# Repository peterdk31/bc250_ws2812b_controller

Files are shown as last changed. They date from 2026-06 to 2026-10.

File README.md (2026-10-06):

# Serial LED controller

A Linux daemon that renders WS2812 (NeoPixel) effects on the host and streams
the frames over USB serial to an ESP32, which just clocks them out to the strip.
All the logic — sensors, rules, effects — lives on the host, so changing
behavior never means reflashing the microcontroller.

Built for an AMD BC-250 running its case lighting from CPU temperature and load,
but nothing is board-specific. Co-authored with
[Claude](https://claude.com/claude-code) (Anthropic).

```
host (led daemon)                      ESP32              strip
sensors → rules → effect → frames ──serial──→ SPI/DMA ──→ WS2812
```

## Hardware

- An ESP32 or ESP32-C3 dev board over USB (`/dev/ttyUSB0` or `/dev/ttyACM0`).
  **Prefer the C3**: its native USB lets the firmware tell whether the host is
  actually running, so the boot animation also plays on reboots and on machines
  that keep standby power on their USB ports. A plain ESP32 can't see any of
  that over UART and only plays it after a true power cycle (see
  [How it works](#how-it-works)).
- A WS2812/WS2812B strip: data to the GPIO set as `strip.pin` (default 13), plus
  5 V and GND from a supply that can handle it (not the board's regulator; share
  grounds).
- Optionally, a momentary power button and a wire to the PSU's PS_ON# line —
  the receiver can then stand in for the PS_ON→GND jumper an ATX/FSP supply
  needs before it starts (see [Power switch](#power-switch)).
- For the BC-250 there is a small carrier PCB in
  [`hardware/bc250_carrier`](hardware/bc250_carrier/README.md): the C3 Super
  Mini solders onto it, the PSU's 10-pin Mini-Fit Jr plug goes straight onto
  a header, and the strip, button, sense wire and four PWM fan headers each
  get a labelled connector — the power switch, strip and fan wiring below, on
  one board.

## Getting started

Two things are needed on the host:

- **`g++` and `make`** to build the daemon. On CachyOS (or any Arch) they come
  in the `base-devel` package group.
- **`esptool`** to flash the receiver (plus `curl`, which is preinstalled).
  You do **not** need an ESP32 toolchain — `make flash` downloads a prebuilt
  firmware image.

```sh
sudo pacman -S --needed base-devel    # compiler + make
pipx install esptool                  # ESP32 flasher (or: pip install --user esptool)
```

On Bazzite (immutable base image) `esptool` installs the same way, but
`g++`/`make` aren't in the base image — build the daemon inside a distrobox,
or copy a prebuilt `led` binary over.

Then build, flash, and start:

```sh
sudo make install                            # daemon + systemd unit + default config
sudo make flash                              # download prebuilt firmware + flash the ESP32
sudo systemctl enable --now led-controller
```

`make flash` reads the chip (`target`, default `esp32c3`) and port
(`serial.port`) from the config; override on the command line, e.g.
`sudo make flash PORT=/dev/ttyACM0 TARGET=esp32`. It stops the service during the
write and restarts it after.

### The full BC-250 flash

Everything this repo can put on the receiver — the ATX power switch, the PWM
fans, the BLE phone remote — is described in the config, in the blocks
`power_switch`, `fans` and `ble_remote` (each has its own section below).
`make flash` bakes all three into the receiver's small settings partitions the
same way it already bakes `strip.pin`, so the full flash is the plain one:

```sh
sudo make flash
```

The config is `/etc/led-controller/config.json` when it exists, else the
repo's (`CONFIG=path` overrides). The shipped blocks are all off, so a fresh
box writes all three features off — the shipped `power_switch` block carries
the carrier board's pins with `"enabled": false`, and an explicit `false`
*is* written. That matters only on a receiver whose power switch is already
on: written off, it releases PS_ON# and cuts the machine's power (see [Power
switch](#power-switch)). Flashing such a box from a config that has no
`power_switch` block at all leaves the chip's switch settings alone, so
delete the block, or enable it, before flashing a machine whose power
already hangs on the receiver. Writing the features from one file also arms
the encoders' strictest cross-checks: a pin claimed by two blocks, or by a
block and `strip.pin`, is a hard error. Each feature's section has the `flash-pwr` / `flash-fan` /
`flash-ble` target that rewrites just that block in seconds.

Finally, edit `/etc/led-controller/config.json` for your hardware — at least
`strip.leds`, `strip.pin`, and `serial.port` — then `sudo systemctl
restart led-controller`.

To try an effect directly (stop the service first, it holds the port):

```sh
led /etc/led-controller/config.json rainbow
```

This runs unprivileged once the serial-group membership added by `make install`
is active — that takes effect on your next login; before then, prefix `sudo`.

## How it works

The daemon renders every frame and sends it over serial; the receiver only
displays what arrives. Pin and LED count travel in each frame, so the firmware
is generic and never needs reflashing for a config or effect change.

While the daemon isn't driving the line — at cold boot before it starts, and
after it exits on shutdown — the receiver plays a **boot** and **shutdown**
animation from flash. The daemon renders those too (through the same color
pipeline), records them, and uploads them once at startup; the receiver stores
them and replays them. So editing the boot/shutdown effects also needs no
reflash — just a daemon restart. A fresh, never-recorded board stays blank
until the daemon has run once and uploaded the recordings.

*When* the boot animation plays depends on the board. It always runs from chip
reset until the daemon's first frame. On USB-native chips (the C3 and friends)
it also re-arms whenever the USB host goes away and comes back — the bus
keepalives stop for a few seconds and return — which covers a reboot (shutdown
animation, dark while the host is down, boot animation as it comes back up)
and a power-on where standby VBUS kept the receiver running the whole time. A
plain ESP32's UART carries no trace of the host's state, so it shows the boot
animation only when it genuinely loses power; on a reboot it stays dark after
the shutdown animation until the daemon returns. If the power-on animation
matters to you, get a C3.

The serial baud auto-negotiates: if bytes arrive but no frame decodes, the
receiver cycles through the supported rates until frames validate, then
remembers the working rate in flash. Changing `serial.baud` just needs a
service restart.

## Flashing the receiver

The firmware is a native [ESP-IDF](https://docs.espressif.com/projects/esp-idf/en/stable/esp32/get-started/)
project under `firmware/` (no arduino-cli, no `.ino`). CI builds it for each
target and publishes merged images to GitHub Releases; `make flash` downloads
the one for `TARGET` and writes it — no toolchain needed.

```sh
sudo make flash                     # download prebuilt image + flash (default)
sudo make flash FW_RELEASE=v1.0.0   # pin a release instead of latest
```

The image is written at `0x0` and doesn't touch the NVS or LittleFS partitions,
so a reflash keeps a board's saved state.

**Building from source** is only needed to modify the firmware, or to bake a
non-default `serial.baud` / `host_timeout_ms` into it. It builds inside
Espressif's ESP-IDF container (needs `docker` or `podman` — nothing is installed
on the host, and `make receiver-clean` drops the cached image), or against a
native ESP-IDF if you set `IDF_PATH=...`:

```sh
sudo make flash-source              # build (container/native) + flash
make receiver                       # build only, no flash
```

**Clearing the board's saved state** — the reset switch when the receiver acts
as if it remembers something wrong. Each erases one partition region; the app
and the power-switch wiring (`pwrcfg`) are untouched:

```sh
sudo make clear-nvs                 # remembered baud + strip geometry
sudo make clear-recordings          # stored boot/shutdown animations
```

The daemon re-uploads the recordings on its next start (and the receiver
re-formats the partition), so `clear-recordings` is also how you get past a
stale or half-written slot that the skip-unchanged hash check would otherwise
keep. As with flashing, esptool resets the chip — see the caveat under
[Power switch](#power-switch).

### Receiver debug log

The receiver has no console (the link is the daemon's), so it keeps a small log
ring in RAM and hands it back over the link on request. Set

```jsonc
"serial": { "debug_log": true }
```

and its lines appear in `journalctl -u led-controller` — the recording uploads
and where they went, boot/shutdown replays, host-gone/host-back transitions, the
strip blanking on timeout, and the power switch's own decisions. The ring is in
RAM on a board running from 5VSB, so events logged while the host was down (a
follow-down, a boot replay) drain once the daemon is back. With the flag off the
daemon never asks and the receiver never sends a log line — the only thing it
ever says unprompted is a power-button request (see
[Power switch](#power-switch)).

## Configuration

`/etc/led-controller/config.json`. The first half describes the receiver — the
chip, the link, and everything it does on its own when the daemon isn't
running — the second half the host's rendering:

```jsonc
{
    "target": "esp32c3",        // chip to build/flash for (esp32, esp32c3, ...)
    "serial": {
        "port": "/dev/ttyUSB0", // "none" or "" (or LED_PORT=none) runs headless;
        "baud": 921600,         // omitting the key defaults to /dev/ttyUSB0
        "debug_log": false      // drain the receiver's log to journalctl
    },
    "host_timeout_ms": 5000,    // receiver blanks after this long with no frame —
                                // baked into the firmware by `make flash-source`
                                // only; the prebuilt image always uses 5000
    "power_on": { ... },        // boot/shutdown animations the receiver replays
    "shutdown": { ... },        // (standalone effects only, see below)

    "power_switch": {           // the ATX power button, see Power switch
        "enabled": false,           // enabled + pins: flash-time (make flash-pwr)
        "hold_seconds": 2,          // hold this long for a hard cut     ┐ the four tunings:
        "boot_timeout_seconds": 10, // rail not up by then = release PS_ON# │ live (reload, or
        "sense_low_mv": 800,        //                                     │ the phone's cog
        "sense_high_mv": 2000,      //                                     ┘ on the Power tab)
        "pins": { "ps_on": 3, "button": 1, "button_gnd": null, "sense": 2, "led": 8,
                  "wake": null },   // wake: an OpenPuck's power-on pulse, see Power switch
        "short_press": null         // what the daemon runs on a short press,
                                    // e.g. "systemctl poweroff"; null = ignore it
    },
    "ble_remote": {             // the phone power button + dashboard, see BLE remote
        "enabled": false,
        "name": "BC250",
        "token": ""                 // 8-16 chars; readable by anyone with a shell here
    },
    "fans": [                   // the fans, see Fans — each an input, a curve
        { "name": "pump", "output": "header1",               // and an output (a receiver
          "input": "fallback", "fallback": 65, "boost": 100 }, // header, a pin, or the
        { ... }                                              // host's own pwm output)
    ],

    "strip": {
        "leds": 58,
        "pin": 13,              // ESP32 GPIO driving the strip
        "reverse": false,       // flip so LED 0 is at the far end
        "brightness": 0.2,      // 0..1, linear
        "gamma": "2.2",         // one value, or three ("2.0 2.2 2.4") per R/G/B
        "white_balance": "ffb0f0" // RRGGBB neutral-white gain; ffffff = off
    },
    "sensors": [ ... ],         // hwmon candidates, see Sensors
    "rules": [ ... ]
}
```

Configs from before September 2026 had an `esp32` block and a `sinks.serial`
one; the daemon names the old key and what it became, and exits, rather than
run on a half-read file.

### Checking a config

```sh
led --check /etc/led-controller/config.json   # or: make check
```

Would the daemon start on this file, and is it the file you meant to write?
The check parses it and runs every block through the same validation the
daemon does at startup — retired keys, the fans block, the rules and their
conditions and effect names, the boot and shutdown recordings (rendered, so a
segment that can't record is caught here) — and then the things the daemon
would run on but nobody could have intended: a key that isn't one inside
`serial`, `strip`, `power_switch`, `ble_remote`, a rule or a recording
segment (with a "did you mean" for a near miss), a value of the wrong type, a
color that isn't `RRGGBB`, a LED count over the receiver's 100, an inverted
sense hysteresis, an enabled `ble_remote` without a token. Each is a line
naming the key; any of them fails the check (exit 1). A `note:` line is
something to look at that may be intended — a top-level key the daemon
doesn't read by name (effects see every top-level key as a shared default
setting), or a rule below a catch-all that can never be reached — and
doesn't fail it. It opens no port and sends nothing; the sensor lookups only
say "not found yet" on a box without them.

`make install` runs the check on the deployed file with the freshly built
daemon before it swaps the binary and restarts the service, so a key the new
version retired is reported while the old daemon still runs, not as a crash
loop after; `make install CHECK=0` skips that.

### Live reload

The running daemon watches its config file and picks up a save within a
second or two — rules, effects, sensors, strip settings, the fans block —
with no restart. A change confined to the `fans` or `power_switch` blocks
leaves the running effect alone; anything else drops the current effect and
the matching rule starts afresh (a crossfade on the strip, like any other
switch). `systemctl reload led-controller` (SIGHUP) does the same
immediately. A file that doesn't parse or validate is reported in the journal
and the running config is kept, so a typo costs a log line rather than a
crash loop; fix it and save again. Two things still need more than a reload:
the `serial` block, because the port is opened once (the daemon says so when
it changes; restart), and anything flash-time on the receiver — the power
switch's pins and enable, the board's fan header map, `ble_remote` — which
is `make flash`'s business (the fans' outputs are not: a reload moves them). The power switch's four tunings and `short_press` are
not flash-time: a reload pushes the tunings to the receiver and changes what
a press does at once. Editing `power_on`, `shutdown` or `strip` re-renders
and re-sends the boot and shutdown recordings, which holds the strip for
about a second. Edits from the phone's dashboard take a shorter path: they
are applied live and written into the file by the daemon itself (`fans`,
`strip`, a scene rule's `color`/`level`, the `power_switch` tunings and
`short_press`), which then treats the file's new mtime as its own doing
rather than a change to reload.

### Tuning the colors

`brightness`, `white_balance`, and `gamma` fold into one per-channel lookup
table applied on the host, so they cost nothing per frame.

How to read the values — every knob is per-channel, red green blue:

```
white_balance "b4b0f0"          gamma "1.9 1.8 1.7"
               ││││└┴─ blue            └┬┘ └┬┘ └┬┘
               ││└┴─── green          red green blue
               └┴───── red
```

Two rules cover every adjustment:

- **White balance scales a channel the same at every level.** Lower a pair →
  less of that color, from full white down to the dimmest glow. `ff` = leave
  the channel alone.
- **Gamma changes how a channel *fades*.** A higher number makes that channel
  die away faster as colors dim; full-on and off never move. `2.2` is
  neutral; you only need three different numbers when a tint appears *only*
  at low levels.

So: name the color the white is leaning toward, then move that channel —
down in `white_balance` if the tint is there at full brightness, up in
`gamma` if it only creeps in as things get dim.

Dial the knobs in by symptom, in this order:

1. **Everything too bright or dim for the room** → `brightness` (0..1).
2. **Full white looks tinted** → `white_balance`: lower the channel(s) of
   the tint. White leans green → lower the middle pair (`ffb0f0`). This is
   the strip+diffuser calibration; start from the diffuser table below.
3. **Full white is neutral, but dim white picks up a tint** →
   per-channel `gamma`: raise the tint's channel so it fades faster (dim
   white leans blue → `"2.2 2.2 2.4"`) — or equivalently lower the channel
   that's going missing (dim white leans blue because red drops out →
   `"2.0 2.2 2.2"`).

The `solid` effect exists for exactly this — it puts up a fixed test field
through the normal correction pipeline:

```bash
led /etc/led-controller/config.json solid    # full white: judge white_balance
```

Look, adjust the config, run again. For the gamma step you need *dim* white;
a forced effect has no rule settings, but effects fall back to top-level
config keys, so temporarily add `"level": 0.25` at the top level of the
config (next to `"strip"`) and run `solid` again. Remove it when done.

**From the couch, with the BLE remote:** the shipped config's first rule is
the same test field as a switch — a static color with a level, which doubles
as a plain light when it isn't tuning anything —

```jsonc
{ "if": "file:/tmp/led-static-color", "effect": "solid", "hold": 0,
  "settings": { "color": "ffffff", "level": 1.0 } }
```

— and the phone's dashboard shows every such `file:` rule as a **scene**
with a switch (README [BLE remote](#the-dashboard)). Switch "solid" on, drag
the white-balance sliders on the LEDs tab while looking at the strip
(each release applies to the live strip at once and lands in the config's
`strip` block), pull the scene's `level` slider down for the gamma step,
switch it off. The color picker on the scene changes the rule's `color`, so
the same switch tests a pure red or a warm white. Any `file:` rule with a
`color` or `level` setting gets the same controls; one without is just a
switch (the `/tmp/led-night` rule below, say). Put these rules first so they
win over everything else while on.

`white_balance` is the *total* correction — strip and diffuser combined into
one measured value. Starting points per diffuser (always confirm against
`solid` white):

| Diffuser | `white_balance` | Why |
|---|---|---|
| none / clear cover | `ffb0f0` | just the strip's own green excess |
| white (milky) | `ffb0f0` | near-neutral filter; scatters but barely tints — trim blue a touch (`ffb0e0`) if white reads cool |
| black / smoked film | `b4b0f0` | dark film passes red most, so take the bare-strip value and pull red down ~30% on top of it. Films vary a lot: one measured black window film landed at `b4ffff` instead — its green/blue cut cancelled the strip's own green excess. Pair with per-channel gamma (e.g. `"1.9 1.8 1.7"`) if dim white still drifts |

Low brightness costs no smoothness: the corrected values ride the wire with 8
extra fractional bits and the receiver rounds them away with a temporal dither
at its own strip-refresh rate (several hundred Hz — far above flicker fusion),
so dim gradients glide instead of stepping or shimmering. There is nothing to
configure; the old `dither` key is gone (this needs receiver firmware from the
same version — reflash once after updating). A change to `strip` re-renders
the boot/shutdown recordings so they carry the new colors — on a hand edit as
part of the reload, after a phone edit ten seconds after the last slider
moved (each re-render holds the strip for about a second).

### Sensors

`sensors` is an ordered list of `chip:label` hwmon candidates; the first present
wins (a bare chip name means its `temp1_input`). Used by `temp` conditions.
The daemon keeps rescanning until one appears. The default
covers the BC-250 (`k10temp:Tctl`, then the NCT6686D under either nct driver).
Two more kinds of candidate take the same slot: `pmbus:CPU VRM` / `pmbus:GPU VRM`
read the BC-250's VRM controller over I2C, and `file:/path` reads a file
holding one temperature — both described under [Fans](#fans), where they are
also fan sources.

### Rules

Evaluated top to bottom every 0.5 s; the first rule whose `if` holds wins. A rule
without `if` always matches (put a catch-all last). No match → strip dark.

```jsonc
{
    "if": "proc:gamescope & temp>75",
    "effect": "ember",
    "hold": 5,                       // min seconds since last switch (default 0)
    "for": 3,                        // condition must hold this long to count (default 0)
    "settings": { "speed": 1.4 }     // effect-specific
}
```

Switches crossfade over the top-level `crossfade_ms` (default 600; 0 =
instant). `for` is an on-delay on the condition: it has to have held for that
many seconds before the rule matches, so a brief load spike never starts a
load rule. Dropping out is immediate. `hold` is the blunter guard: no switch
*into* this rule until that long after the last switch, whatever the
conditions did meanwhile.

### Conditions

| syntax | true when |
|---|---|
| `always` | always |
| `temp>N` / `temp<N` | sensor temperature above/below N °C |
| `cpu_load>N` / `cpu_load<N` | CPU busy above/below N % (bare `cpu_load` = `>20`) |
| `gpu_load>N` / `gpu_load<N` | amdgpu busy above/below N % (bare `gpu_load` = `>20`) |
| `proc:NAME` | a process with that name is running (15-char kernel limit) |
| `steam_dl` | a Steam download is actively moving bytes |
| `audio_playing` | system audio is actually playing (see below) |
| `file:/PATH` | the file exists |
| `!COND` | negation |
| `A & B` | both hold |
| `A \| B` | either holds (`&` binds tighter; no parentheses) |

`file:` is the external control surface — `touch /tmp/led-night` to switch modes,
`rm` to switch back. A rule whose whole condition is one `file:` path is also
a **scene** on the phone's dashboard ([BLE remote](#the-dashboard)): a switch
the daemon flips by creating or removing that file, with a color picker or a
level slider when the rule's settings carry `color` or `level`.

The `steam_download` effect turns the strip into a live download progress bar
(percent driven by network throughput; green pulse at 100%). Reading other
users' Steam libraries needs the daemon running as root (the systemd unit does).

The `audio_*` effects visualise what's playing (combine them with `cycle` for
variety — they share one capture stream and auto-gain, so hopping between them
is seamless). The effects capture samples by spawning `parec` (or
`pw-record`) on the default sink's monitor while active; running as root
(the systemd unit does) lets it find the user session's PipeWire socket under
`/run/user/`.

The `audio_playing` condition costs nothing while the system is silent (one
procfs read per tick). Once anything is audible it asks the sound server for
its playback stream list (`pactl -f json list sink-inputs`, spawned
asynchronously about once a second): an uncorked stream means playing, corked
or none means paused/stopped. That verdict is immune to quiet passages inside
the music and reacts to pause/resume within a second or two. It is also the
only source of truth: if the list can't be fetched while audio is audible
(no `pactl`, no reachable session), the condition stays false and a note is
left on stderr. Placing the rule *below* the `load` rule means load takes the
strip whenever it's active and music has it otherwise — first matching rule
wins.

## Effects

| name | description | key settings (defaults) |
|---|---|---|
| `alarm` | urgent heartbeat throbbing from the center | `color` (ff0000), `pulses_per_second` (2) |
| `audio_music` | audio-reactive bloom from the center: loudness sets its reach, bass pumps it and sends crests to the tips | `palette` (4a00b4,e02090,ff9c28), `pulse` (0.8), `gain_seconds` (6) |
| `audio_ripple` | audio-reactive: each bass hit sends a wave crest with a luminous wake racing from the center to the tips, reflecting back off them, colors walking the palette per beat | `palette` (0030a0,00c0e0,8040ff), `travel_seconds` (1.0), `sensitivity` (1.0), `reflect` (0.6) |
| `audio_spectrum` | audio-reactive liquid analyzer: a spring-loaded bar grows from the strip start with the loudness, a meniscus shine on its tip, bass pumping its base and treble its tip, a peak dot falling back with a comet tail between hits | `palette` (00e6b4,3a56ff,ff2e88), `pump` (0.7), `bounce` (0.6), `peak_color` (ffffff) |
| `aurora` | slow drifting color curtains walking a palette | `palette` (10ff80,10a0ff,8040ff), `speed` (1.0) |
| `boot` | calm bloom from the center into a full wash, then exhales into a dim hold | `intro_seconds` (7), `color` (ffffff) |
| `breathe` | palette wash on a slow breath with a drifting bright band | `palette` (0d4a44,30e090), `period_seconds` (3.5) |
| `button_off` | experimental: the lit strip collapses into the power button | `duration_seconds` (1.4), `color` (ffffff), `reverse` (true) |
| `button_on` | experimental: light spills out of the power button, then pulses | `spread_seconds` (2.5), `period_seconds` (4), `color` (ffffff) |
| `caustics` | underwater light caustics: two multiplied noise fields carve bright wandering filaments that merge and dissolve | `palette` (020818,004060,00b0c0,a0fff0), `sharp` (1.5), `gain` (3.2) |
| `comet` | Larson scanner with a fading tail, optional mirror | `palette` (8040ff,30c0ff), `sweeps_per_second` (0.7), `tail_pixels` (8) |
| `cycle` | rotates through a list of other effects | `period_seconds` (30), `effects` (list) |
| `drift` | soft palette glows wandering over a dark base | `palette` (2858ff,30d0b0), `blobs` (3), `speed` (1.4) |
| `ember` | slow warm aurora-style flow through an ember palette | `palette` (2a0a00,ff7d1e), `speed` (1.4) |
| `ink` | drops of ink recolor the whole strip in slow sweeping fronts, a glistening rim on each leading edge | `palette` (6a00ff,0080ff,00d0a0,ffb000,ff2060), `period_seconds` (10), `spread_seconds` (4) |
| `lava` | lava lamp: soft blobs drift, meet and merge into hotter spots | `palette` (ff0050,ff5a00,ffd000,00e5ff,7a00ff,ff00d0), `blobs` (4), `speed` (5.0) |
| `load` | CPU/GPU bars from center over a palette wash, each with a heartbeat that quickens under load; each side's palette window slides toward the hot end with its load | `palette` (00e0c0,2060ff,a040ff,ff4060,ff9000), `heat_span` (0.45), `color_drift` (0.3), `pulse` (0.5) |
| `load_boil` | CPU/GPU load as a lava lamp: each half's blobs boil harder and shift toward the palette's hot end with that side's load | `palette` (00e0c0,2060ff,a040ff,ff4060,ff9000), `blobs` (2), `boil` (2.5) |
| `orbit` | binary stars: glow pairs orbit a shared center, whipping through conjunctions that bloom white-hot | `palette` (1030ff,00d0ff,c080ff,ff40a0), `pairs` (2), `origin` (0.5) |
| `plasma` | drifting sines + noise walking a palette | `palette` (0040ff,00d0a0,c040ff,0040ff), `speed` (1.4) |
| `pulse` | soft palette rings expanding from the center | `palette` (5028ff,30d0ff), `period_seconds` (4) |
| `rainbow` | scrolling hue cycle with shimmer | `cycles_per_second` (0.9) |
| `shoreline` | waves roll in from both ends, decelerating and whitening into foam as they break at the center | `palette` (003048,00a090,60e0c0), `period_seconds` (6), `foam_color` (ffffff) |
| `shutdown` | CRT-style collapse to a point, then a slow phosphor fade | `duration_seconds` (5.0), `color` (0028ff) |
| `silk` | tide through a drifting warp field: color bands stretch, buckle and fold like fabric in a breeze | `palette` (3a1078,c03080,ff9040,20b0c0,3a1078), `fold` (0.5), `sheen` (0.3) |
| `solid` | fixed color everywhere — the color-calibration test field, or a plain static light | `color` (ffffff), `level` (1.0) |
| `steam_download` | live Steam download bar, green pulse at 100% | `palette` (d4009c,ff5a1e,ffd23c), `done_color` (00ff66) |
| `tide` | a palette gradient sliding and breathing | `palette` (102060,1890d0,30d0a0,8040ff,102060), `speed` (1.4) |

Colors are `"RRGGBB"` or `"#RRGGBB"`; a `palette` is several separated by
non-hex (`"2a0a00, ff7d1e"`), spaced evenly and blended in RGB. Every effect
also takes `frame_ms` (delay between frames; default 16 ≈ 60 fps).
Settings resolve per-rule first, then top-level config, then the defaults above.

### Boot & shutdown animations

Set `power_on` / `shutdown` to any standalone effect, or a `sequence` played
into one recording — typically a one-shot intro into a looping idle:

```jsonc
"power_on": {
    "sequence": [
        { "effect": "boot",    "record_seconds": 4,
          "settings": { "intro_seconds": 3, "color": "ff7818" } },
        { "effect": "breathe", "record_seconds": 5, "loop": true,
          "settings": { "palette": "2a0a00,ff7818", "period_seconds": 5 } }
    ]
},
"shutdown": { "effect": "shutdown", "settings": { "color": "0028ff" } }
```

The last segment's `loop` decides the tail (loop from its first frame, else hold
the last frame); earlier segments play once. For a seamless loop make the
looping segment's `record_seconds` a whole multiple of its period. The whole
recording replays at one rate — the first segment's `frame_ms` — so a later
segment's own `frame_ms` has no effect on replay. Finite
effects (`shutdown`) record to completion; open-ended ones (`boot`) record for
`record_seconds`. Unchanged recordings aren't rewritten to flash (a hash is
compared), so wear is near zero. `cycle` can't be a slot (it needs the JSON
config).

Preview a slot exactly as the receiver will replay it, without hardware:

```sh
make virtual-strip && ./virtual-strip                    # one terminal
LED_PORT=none ./led config.json --preview power_on       # another
```

## Power switch

An ATX/FSP supply (like the BC-250's FSP500-30AS) doesn't start until its
PS_ON# line (the green wire) is pulled to ground — normally a permanent
jumper. With the receiver powered from the PSU's **5VSB** standby rail, it can
drive that line instead and act as the machine's power button
(after [Thunkar/bc250-esp32-switch](https://github.com/Thunkar/bc250-esp32-switch),
minus its WiFi/BLE):

- **Press** the button while off → PS_ON# is sunk to ground, the PSU starts,
  the board boots. It fires on the press itself, not on the release, so that
  keeping it held afterwards is free to mean the failsafe below.
- **Short press** while the machine is up → the ordinary PC power-button
  gesture: the OS is asked to shut itself down gracefully. The receiver can't
  do that itself, so it asks over the link and the daemon runs the
  `power_switch.short_press` command (`"systemctl poweroff"`); the machine
  then powers itself off and the sense wire's follow-down releases PS_ON#.
  **This needs `short_press` set to a command** — it ships `null`, so a box
  that hasn't opted in ignores the press (and says so in the journal). If nobody answers within 3 s
  — daemon down, no OS yet, feature off — the request is dropped and the
  feedback LED blinks fast for a moment, because otherwise an unheard press
  looks exactly like a broken button. Nothing about this path touches PS_ON#:
  the worst case is a machine that stays on.
- **Hold** for 2 s while on → PS_ON# is released — a hard power-off for a
  wedged machine, and the answer to an OS that accepts the graceful request and
  then hangs. (Only a press that began while the machine was already up can do
  this: the press that powered it on never turns it back off, however long it's
  held.)
- With the **sense** wire (BC-250: TPMS1 pin 9, ~2.9 V while the board is
  up): a graceful OS shutdown is followed down (the sense line drops, the
  receiver releases PS_ON# so the PSU turns off too), and a board that never
  comes up within 10 s releases the PSU instead of leaving it energized.
  The wire is optional but strongly recommended — without it both are
  skipped, and after every OS shutdown the PSU stays energized, holding
  PS_ON#, until a 2 s long-press; what's left is less a power button than a
  toggle that sticks on.
- **Keep holding the button** → the failsafe: while it is physically held the
  sense line cannot power anything off. Follow-down is suppressed, and the boot
  timeout is parked, counting its 10 s from the release instead of from the
  power-on. This is the way out of a mis-wired sense line, which is otherwise
  self-sealing: a sense pin that reads low while the board is really up (wrong
  pin, wire fallen off, thresholds wrong) makes the boot timeout cut the PSU
  ~10 s into every boot, so the machine can never stay up long enough to
  reflash the config that would fix it. Press to power on, keep your finger
  down, and the machine stays up while you reflash — including *through* the
  reflash: a receiver that comes up with the button already held adopts that
  press as the failsafe, and won't read it as a fresh 2 s force-off either.
  The sense line is still sampled and logged while held (see the debug log
  below) — that log is how the right pin and thresholds get found.

Wiring (the shipped `power_switch.pins`, for the ESP32-C3; `null` = not wired):

| receiver pin | connects to |
|---|---|
| GPIO3 (`ps_on`) | gate of an N-channel MOSFET that sinks PS_ON# to ground (see note below) — **not** PS_ON# directly |
| GPIO1 (`button`) | momentary switch terminal A (internal pull-up, pressed = low) |
| `button_gnd`: `null` when the switch is wired to a real GND (the carrier board), else e.g. GPIO21 | switch terminal B — driven low as a local ground, so the button needs no run to a real GND. (GPIO21 is U0TXD: free while the host link is USB) |
| GPIO2 (`sense`, `null` = not wired) | optional board-power sense, e.g. BC-250 TPMS1 pin 9, which is the board's main **3.3 V rail**. Emphatically *not* pin 15 (`3VSB`): that stays up whenever PS_ON# is held, so it reads like a working sense wire and then never fires follow-down or the boot timeout. Read as an averaged ADC voltage with hysteresis (`sense_low_mv` / `sense_high_mv`); the ADC saturates near 3.1 V, so a healthy rail logs ~2.9–3.1 V |
| GPIO8 (`led`, `null` = none) | optional feedback: the board's own little LED *blinks* while the button reads pressed (and through a wake pulse), so the wiring can be eyeballed without a PSU. GPIO8 is the plain onboard LED on common C3 dev boards; a blink shows regardless of the LED's polarity |
| `wake` (`null` = not wired; GPIO20 on the carrier's J11) | optional **wake input**: a 3.3 V active-high pulse from another device that wants the machine on — see *Waking from an OpenPuck* below. Internal pull-down; a rising edge while OFF powers on, and a pulse in any other state is dropped, so it can never shut anything down. Because it can do nothing else, this is the one pin that also **moves at runtime**, like the tunings: the daemon pushes `pins.wake` at startup and on a reload, and the phone's power settings pick it from the receiver's free pins (see [The dashboard](#the-dashboard)) |
| 5VSB + GND | PSU standby rail, so the receiver runs while the machine is off — **read the warning below before also plugging in USB** |

> ⚠️ **Critical — 5VSB and USB at the same time.** In this role the receiver
> is powered from 5VSB *and* still plugged into the host's USB for the LED
> link. That is two hard-paralleled 5 V supplies: most dev boards tie the USB
> connector's VBUS straight to their 5 V pin, so whichever rail sits higher
> pushes current into the other with nothing to limit it. Whenever the
> machine is off — the normal state for a power button — that means the
> receiver back-feeds the host's **dead** USB port continuously: current
> flows backwards through the port's VBUS circuitry (which is not designed
> for it and can be damaged) and phantom-powers part of the motherboard's
> 5 V rail off the PSU's small standby supply. **Cut or unpin the 5 V wire
> (red) in the USB cable**; keep D+, D− and GND. The receiver then runs
> solely from 5VSB and USB still works fully as a self-powered device —
> flashing, the LED link and the USB host-presence detection are unaffected.
> Some dev boards do have a protection diode between the USB jack and the
> 5 V pin, which blocks the back-feed — but many compact clones don't, so
> don't bet the port on it.

**The PS_ON# pin drives a MOSFET, not PS_ON# directly.** A 3.3 V pad can't be
tied to PS_ON#: the line is pulled to 5 V inside the PSU, and letting it rise
back-feeds the pad's clamp diode so it never reaches a clean "off" — direct
drive doesn't work. Wire a small N-channel MOSFET (a **2N7000** is plenty for
PS_ON#'s ~1 mA) as a low-side switch: **gate** ← the `ps_on` pin, **source** →
GND, **drain** → PS_ON#. `ps_on` HIGH turns the MOSFET on and pulls PS_ON#
to ground (PSU on); LOW releases it (PSU off). Add a **gate pull-down (~100 kΩ,
gate → GND)** so the MOSFET stays off whenever the pad isn't driving it — at
power-up before the firmware runs, during a reset, and on the `"enabled": false` release
path; without it a floating gate could start the PSU on its own. (100 kΩ is
ample: the gate is a near-pure capacitance, and the line switches about once
per boot.)

```
ESP32-C3  (running on the PSU's 5VSB standby rail — see the USB warning above)
──────────────────────────────────────────────────────────────────────────────
  5V      ──  PSU 5VSB
  GND     ──  PSU GND
  GPIO4   ──  WS2812B strip DIN   (strip.pin)        ── the LED output; daemon-set
  GPIO3   ──  2N7000 gate         (pins.ps_on)       ── PS_ON# via MOSFET, below
  GPIO1   ──  button  N (common)  (pins.button)
  GPIO21  ──  button  NO          (pins.button_gnd)  ── or a real GND, and null here
  GPIO2   ──  BC-250 TPMS1 pin 9  (pins.sense)       ── board sense (3.3 V rail)
  GPIO8   ──  onboard LED         (pins.led)         ── feedback, no wiring
  GPIO20  ──  OpenPuck pin 017    (pins.wake)        ── optional wake pulse; null here

PS_ON# drive — low-side N-channel MOSFET (2N7000)
──────────────────────────────────────────────────────────────────────────────
                 PS_ON#   (PSU "green" wire; the PSU pulls it up to +5 V)
                    │
                    │ D (drain)
                 ┌──┴──┐
   GPIO3 ──┬─────┤ G   │   2N7000
           │     └──┬──┘   (N-channel)
       [100 kΩ]     │ S (source)
           │        │
          GND      GND

   GPIO3 HIGH → MOSFET on  → PS_ON# pulled to GND  → PSU ON
   GPIO3 LOW  → MOSFET off → PS_ON# floats to +5 V → PSU OFF
   The 100 kΩ gate→GND pull-down holds it OFF whenever GPIO3 isn't driving.

Button (momentary; N = common, NO = normally-open)
──────────────────────────────────────────────────────────────────────────────
   Pressing shorts N→NO. GPIO1 idles high on its internal pull-up; GPIO21 is
   driven low as the button's local ground, so a press pulls GPIO1 low.
   Press = power on (on the press edge), 2 s hold while up = force off, and
   held = sense failsafe.  (Wire N and NO — NOT the NC terminal.)

LED strip (WS2812B)
──────────────────────────────────────────────────────────────────────────────
   DIN ← GPIO4; the strip's +5 V and GND come from the PSU's main 5 V rail (a
   26-LED strip is more than the 5VSB rail should carry), sharing a common GND
   with the ESP32-C3. GPIO4 is the C3 build's value — the strip pin is the
   daemon's `strip.pin` (pushed at runtime, cached in NVS), not one of the
   `power_switch.pins`, so it just must not collide with the pins above or the C3's
   flash pins (GPIO12–17). The repo's default `strip.pin` is 4 to match the
   default `TARGET` (esp32c3); a plain ESP32 wants something like 13.
```

Three pin caveats. First, the sense pin is **GPIO2** — one of the C3's
strapping pins, and that's fine. It was briefly moved to GPIO0 on hygiene
grounds (TPMS1 pin 9 sits at 0 V whenever the machine is off, and Espressif
recommend pulling GPIO2 up for glitch immunity), which turned out to be a bad
trade: the theory was thin — the same design guidelines are explicit that on
the C3 GPIO2 *"does not determine SPI Boot and Joint Download Boot mode"*
(that's GPIO9, with GPIO8 supporting), and GPIO2 was verified booting fine on
real hardware with pin 9 grounded — while the cost of a default that doesn't
match the wire in the machine is severe, because a sense pin reading a rail
that isn't there means the boot timeout cuts the PSU 10 s into every boot (this
happened; the failsafe above exists because of it). So GPIO2 it is, and
`tools/pwrcfg.py` no longer warns about it. Severity *is* chip-specific,
though: on a plain ESP32 the strapping pins select boot mode outright (GPIO0
low = download boot), so there a sense line grounded half the time really can
stop the chip booting — the encoder still warns for those. Second, if the sense
wire isn't connected, set `"sense": null` rather than leaving the input
floating: a floating ADC pin reads noise, and the boot timeout may cut the PSU
seconds after every power-on. Third, the defaults are C3-specific: on a plain
ESP32, GPIO1/3 are its UART0 console and 0/2 are strapping pins — pick
different ones.

**Waking from an OpenPuck.** An [OpenPuck](https://github.com/safijari/openpuck)
(open firmware for a SuperMini nRF52840 that stands in for the Steam
Controller 2's puck) has a *ColdBoot* feature: when the paired controller's
Steam button is pressed while the host reads USB-unmounted, the puck drives a
GPIO high for 300 ms — on a motherboard, through a transistor across the
power-switch header. Here the receiver is the motherboard, so the transistor
goes: the puck's ColdBoot pin (silkscreen `017`, its default) straight to
the `wake` pin, puck GND to the GND beside it — both are 3.3 V logic. It
is a plain active-high edge, debounced like the button and read with the
internal pull-down, so an unplugged or unpowered puck reads idle. Two rules
make it safe to hang a stranger's output on the machine's power: it is
edge-triggered and **armed only after reading idle for 1 s** (both boards come
up together on 5VSB and the puck's pin floats until its firmware runs; a level
held high across a receiver reset is not a press), and a pulse in BOOTING or
ON is **logged and dropped** — on a PC that same pulse would mean "shut down",
here it can only ever mean "on", whatever the puck's own gating decides.
Build the puck with `EXTRA_FLAGS="-DOPK_PWR_SWITCH=1"`; its pulse polarity is
a build flag too (`PWR_SWITCH_ACTIVE`), and the receiver expects the default,
active-high.

Power the puck from 5VSB so it keeps listening while the machine is off: on
the SuperMini that is its **BAT** pin (the board has no pin on the USB side —
the Pro Micro "RAW" position is unconnected). BAT reaches the board's supply
node through a P-MOSFET that the host's USB VBUS switches off, and is isolated
from the USB connector by the charger and a Schottky (BAT60B), so 5VSB cannot
back-feed the host's port and the puck's USB cable stays **intact** — it must:
the nRF's VBUS pin sits on the connector side, and the host's VBUS dropping
when the machine dies is what clears OpenPuck's "USB mounted" gate. (This is
the one place the 5VSB-and-USB warning above does *not* apply; the receiver's
own dev board has no such diode.) 5 V on a charger's battery pin is off-label
but harmless — the charger sees a full cell and idles, the LDO takes up to
6 V; a 1N5817 in series brings it nearer a battery's voltage if that bothers
you. Once the machine's OS enumerates the puck it stops firing on its own; a
second Steam press during BIOS lands in BOOTING and is dropped.

The feature is **off until opted into**: its settings are the config's
`power_switch` block, and they live on the receiver in a small dedicated flash
partition (`pwrcfg`), not in the firmware image, so the prebuilt image works
and pins change without touching source. `make flash` writes the partition
from the block alongside a normal flash, and `make flash-pwr` writes *only*
that partition — re-pinning takes a couple of seconds and keeps the installed
firmware. Three guardrails to know about:

- **A config with no `power_switch` block leaves the chip's settings alone.**
  The fans and the remote are written *off* in that case, harmlessly; the
  power switch written off releases an asserted PS_ON# once the receiver
  reboots — it cuts the machine's power — so only an explicit
  `"enabled": false` does that. Put the jumper back first if the machine's
  power already hangs on the receiver.
- **The firmware must be v1.6.0 or newer** — that's where the `pwrcfg`
  partition first exists. `make flash-pwr` against an older installed
  firmware (or an older `FW_RELEASE` pinned) writes a sector that firmware
  never reads: a silent no-op. Update the firmware itself first. (Individual
  settings added later are simply ignored by firmware that predates them —
  e.g. v1.6.0 exactly reads everything but the `led` pin, and the `wake` pin
  needs the firmware from Sep 2026 on.)
- The block is validated before anything is written: `tools/pwrcfg.py`
  rejects pins the firmware would silently drop (nonexistent on `target`,
  SPI-flash or host-link pads, a non-ADC sense pin, a collision with the
  `strip.pin` LED data pin or a fan header) and nonsense tunings (inverted
  hysteresis thresholds), and an unknown or missing key. The receiver has no
  console, so a config it can't use would otherwise just look like a dead
  button.

```sh
sudo make flash          # firmware + the config's power_switch block (and the fans', and the remote's)
sudo make flash-pwr      # rewrite only the power_switch block: seconds
```

The switch runs standalone — no daemon involved; the button matters exactly
when the host is off. Only `short_press` is the daemon's.

Of the block, the **pins and `enabled` are flash-time only** — a pin the
machine's power hangs on is nothing to change from a phone, and the flash
tool is where the wiring gets checked. The four **tunings** are not:
`hold_seconds`, `boot_timeout_seconds`, `sense_low_mv` and `sense_high_mv`
are values the switch's task reads on every poll, so the partition's are
just their defaults. The daemon pushes the config's values to the receiver
at startup, on a [live reload](#live-reload) and after a phone edit
(command `0x0E`), the receiver applies them at once and keeps them in NVS
layered over the partition's — re-flashing `pwrcfg` with *different*
tunings wins again, the fans' rule — and the [BLE dashboard](#the-dashboard)
edits them from the Power tab's cog, against the sense wire's live reading.
`short_press` follows the same path on the daemon's side: a reload or a phone
edit changes what a press does without a restart.

**Reflashing caveat:** once the machine's power hangs on this pin, remember
that flashing the receiver *from that machine* resets the chip mid-write. On
a **C3** the firmware defends itself: the asserted level is latched in the
always-on pad domain (`gpio_hold_en`) so it rides through the chip's internal
resets — including into the flashing ROM — and on any reboot that isn't a true
loss of standby power the intent is restored first thing at boot, read from
NVS *or from the still-latched hold itself*, so even a reflash or `make
clear-nvs` that empties NVS can't talk the new firmware into releasing the
pin. (That double-check matters: `make flash` used to overwrite the NVS
region with the merged image's padding — it skips it now — and the freshly
booted firmware, finding no saved intent, would cut the machine's own power
at the end of the flash, hard enough to corrupt files on it.) Still, verify a
`make flash` on your wiring once — with a temporary PS_ON→GND jumper in
place — before trusting it with unsaved work. On a
**plain ESP32 neither defense works for flashing**: esptool resets it by
pulling the EN pin, a genuine chip power cycle that drops pad holds and reads
as a power-on reset. Flash one from another machine or with the jumper in
place. (Crashes/watchdog resets are still ridden out there too, provided
the PS_ON pin is one of its RTC-capable pins: 0, 2, 4, 12–15, 25–27, 32, 33.)
After a genuine 5VSB power loss the machine always stays off until the button
is pressed.

## Fans

The receiver drives up to six 4-pin PWM fans at the fan spec's 25 kHz —
built for an AIO liquid cooler, whose pump is just another 4-pin channel. The
fans are powered from the PSU directly (they draw far more than a GPIO ever
could); only their PWM input wires connect to the receiver, with all grounds
common. The receiver's 3.3 V push-pull output is comfortably above the spec's
~2.8 V logic-high threshold, so standard 4-pin fans read it fine; the fans'
tach (sense) wires stay unconnected. On the carrier board the four headers are
labelled FAN1–FAN4; elsewhere, see the wiring table below. The daemon can
also drive a fan header on the **host itself** — the BC-250's own, on the
NCT6686D — the way CoolerControl does (see [Host outputs](#host-outputs)).

Everything about the fans is the config's `fans` block: a list of fans, each
an **input** read through a **curve** onto an **output**. Every fan has a
`name`, an `output`, an `input` and a `fallback`, a `curve` for every input
but `fallback` (a parked fan's curve and fallback are optional — it drives
nothing), optionally a `boost`, and
optionally its tunings — `hysteresis`, `ramp`, `boost_seconds`. The list's
order is the phone's; there is nothing global in the block.

```jsonc
"fans": [
    {
        "name": "pump",             // log lines and the phone's card
        "output": "header1",        // the receiver's header 1 (FAN1 on the carrier)
        "input": "fallback",        // fixed speed: the fan runs its fallback, always — no curve
        "fallback": 65,             // AIO pumps want a steady 65-100
        "boost": 100,               // the duty for the first boost_seconds after power-on
        "boost_seconds": 5          //   (no boost key, or null = none; default 5 s)
    },
    {
        "name": "radiator",
        "output": "header2",
        "input": "temp",            // the top-level `sensors` pick, in °C
        "curve": "45:35 60:55 75:100",   // input:percent points, linear between, flat beyond the ends
        "hysteresis": 3,            // the temperature must fall this many °C before the fan slows (default 3)
        "ramp": 5,                  // max percent per second on the way down; speed-ups are immediate (default 5)
        "fallback": 100             // what it runs when the input can't be read, and when no daemon drives it
    },
    {
        "name": "exhaust",
        "output": "header3",
        "input": "gpio:0",          // the BC-250's own fan header's PWM wire, on receiver GPIO0: the
        "curve": "0:25 100:80",     //   RECEIVER reads it and runs this curve — daemon or no daemon.
        "ramp": 0,                  //   The board's firmware already smooths its output, so no ramp on top
        "fallback": 100
    },
    {
        "name": "board fan",
        "output": "nct6686:pwm2",   // the BC-250's own fan header, driven by this daemon (a host output)
        "input": "k10temp:Tctl",
        "curve": "50:30 80:100",
        "fallback": 60
    }
]
```

**`output`** is what the fan drives:

| output | drives |
|---|---|
| `headerN` | header N of the receiver's board — the board's header → GPIO map (`tools/pincheck.py` `FAN_PINS`; the carrier's FAN1–FAN4 = GPIO5, 6, 7, 10) |
| `gpio:N` | a receiver GPIO by number, for a hand-wired build |
| `chip:pwmN` | a pwm output of the host, driven by the daemon — see [Host outputs](#host-outputs) |
| `""` | nothing: the fan is *parked*, its settings kept for later. Its input still shows on the phone — a host fan header as the input (`"output": "", "input": "nct6686:pwm2"`) is how to watch what the board runs there, duty and rpm |

Every output is a runtime setting: the phone can move a fan to another header
or pin, and the receiver attaches its PWM there at once. The fans on receiver
outputs take the receiver's six PWM channels in list order. A receiver header
no fan names is **not driven** — and that is not "off": a 4-pin fan with a
floating PWM input runs at full speed, per the fan spec. A fan you want
*stopped* is one with `"input": "fallback", "fallback": 0` (most fans stop at
0 % duty; the spec allows a fan to keep a minimum speed instead, so check
yours).

**`input`** is what the curve reads; the x unit of the curve follows it, and
so does *where the curve runs* — on whichever side can read the input:

| input | reads | x unit | runs on |
|---|---|---|---|
| `fallback` | nothing — the fan runs its `fallback` value, always; no `curve` | — | receiver (a host output: daemon) |
| `gpio:N` | the duty of a PWM signal on the receiver's GPIO N — a fan header's PWM wire (the BC-250's own, say), so the receiver follows the board's BIOS curve with no daemon and the machine off. A receiver output only | % | receiver |
| `esp32_temp` | the receiver chip's own temperature sensor — a rough reading of the case air around the receiver (see below). The receiver runs the curve itself, with no daemon and the machine off. A receiver output only, on a chip with the sensor (the C3 yes, the plain ESP32 no) | °C | receiver |
| `temp` | the top-level `sensors` pick | °C | daemon |
| `chip:label` | any hwmon temperature, same syntax as `sensors` (`amdgpu:edge`, `nct6686:CPU`; a comma list of candidates works too). The phone's picker lists every labelled one the machine has, with its reading; so does `--fan-status` | °C | daemon |
| `pmbus:CPU VRM` / `pmbus:GPU VRM` | the BC-250's two VRM rails, read from the board's PMBus controller over I2C by the daemon itself — see [VRM and GDDR6 temperatures](#vrm-and-gddr6-temperatures) for the two-wire mod that exposes the bus. Listed in the picker once the controller answers | °C | daemon |
| `smu:VRAM hotspot` / `smu:VRAM average` / `smu:VRAM 0`..`7` | the eight GDDR6 chips — the hottest, the mean, or a named chip — through the `bc250_memory` kernel driver, or read from the SMU by the daemon when a patched BIOS has unlocked it; see [VRM and GDDR6 temperatures](#vrm-and-gddr6-temperatures). Code 80 saturates the sensor at 120 °C. Listed in the picker once patched | °C | daemon |
| `file:/path` | one temperature in a plain file, in millidegrees (the sysfs convention: 1000 and up) or degrees. For telemetry some other program publishes as files. Files under `/run/bc250` named `*_temp` are listed in the picker; any other path goes in through its *Temperature file…* row | °C | daemon |
| `chip:pwmN` | a hwmon pwm *output* — the board's own fan header, i.e. what its BIOS fan curve is asking for, read over the host instead of a wire. The phone's picker lists each one with its rpm. Not one the daemon drives (it would read its own duty back), so not the fan's own output either | % (0..255 read as 0..100) | daemon |
| `cpu_load` / `gpu_load` | the rule conditions' readings | % | daemon |

**`curve`** is `x:percent` points in one string (up to eight), linear
between points and flat beyond the ends, so a curve never has to spell out 0
or 100 on the x axis. Floors, ceilings and scaling all live in the curve
(`"0:25 100:80"` is a floor of 25 scaled to 80 %). A `fallback` input takes
no curve and every other input needs one (a parked fan's is optional) — the daemon (and
`make flash`) refuse the other combinations, along with an unknown or missing
key, so a typo is a startup error rather than a silently odd fan. A `gpio`
curve's inputs are whole percents 0..100, an `esp32_temp` curve's whole °C
0..100 (both travel to the receiver as bytes).

**`gpio:N`** as an input is the wired twin of `chip:pwmN`: a two-wire lead
from the fan header's PWM (pin 4) and GND pins to a free receiver GPIO and its
GND — only those two, never the header's +12 V, which would parallel the
board's fan rail with the PSU's. The receiver reads the pin with its internal
pull-up (a PC fan header drives its PWM open-drain, so the level is the
receiver's own 3.3 V; a push-pull 5 V driver needs a series resistor — check
with a meter), samples the duty four times a second, and runs the curve with
the fan's own `ramp`. Unplugged, the pin reads high — 100 %, the fan spec's
own answer to a missing signal. On the carrier board the free pins are GPIO0,
20 and 21 on J11 (each with a GND beside it; 20 and 21 are also the J5 UART
candidates), and `make flash` refuses anything else: a header's pin, another
fan's output, the strip, the power switch's pins, the flash pads, the USB
pair, and the strap pins (8, 9 — a PWM at 0 % is a pin held low at reset,
which is the download-mode strap). A pin that arrives at runtime (a phone
edit, a daemon push) is checked again on the receiver, which logs a refusal
and runs the fallback. The phone never has to guess: the receiver publishes
the pins that pass that check, for inputs and for outputs, and the editor
lists them.

**`esp32_temp`** reads the temperature sensor inside the receiver's own
chip — nothing to wire. It is the die's temperature, not the air's: the chip
sits a few degrees above the air around it (more with the radio busy), and
the offset varies from chip to chip, so treat it as a trend of the case air
near the receiver rather than a thermometer, and write the curve against what
it actually reads (the phone's picker shows it live). The receiver reads it
once a second and smooths it over ~8 s, so it has no `hysteresis` of its own
(the key is refused); `ramp` applies as usual. Its use is a curve that keeps
working with no daemon — a case fan that tracks how warm the box is, on a
bench build or while the host is booting — not a replacement for the host's
real temperatures. The page shows the reading whether or not a fan follows
it; a receiver with no sensor doesn't offer the input, and one that is sent
it anyway runs the fallback.

**`boost`** and **`fallback`** are the fan's *standalone* settings — what the
receiver does on its own. Full speed is the safe answer for cooling, which is
why `fallback` is 100 in most examples; a fan with no boost starts at its
fallback instead of boosting. Reading the radiator above as a timeline:

1. Power button pressed. The receiver asserts PS_ON#, sees the rail up, and
   runs the pump (which has a boost) at 100 % for `boost_seconds`.
2. Boost ends; the daemon isn't up yet, so the radiator runs its fallback,
   100 %.
3. The daemon starts, reads the temperature and pushes the curve's 35 %. The
   radiator settles there.
4. The temperature sensor stops reading (a driver unloaded, a thermistor
   unplugged): the radiator runs its fallback until it reads again.
5. The daemon crashes or is stopped under a running machine. Fifteen seconds
   later the receiver notices the silence and the radiator goes back to 100 %.
6. Normal shutdown. The daemon's shutdown notice says the machine itself is
   powering off, and the receiver *holds* the last live duties instead, so the
   fans wind down from where they are when the PSU cuts — no full-speed blip.
   (A plain `systemctl restart` or `stop` doesn't say that, and the fans fall
   back as in step 5 if no daemon comes back.)

The pump, a `fallback` input, runs 65 % from step 2 on and never notices the
daemon; the exhaust, a `gpio` input, follows the board's own fan header from
step 2 on the same way.

Each receiver fan's duty comes from four places, strongest first: the
**boost** while its window runs; the receiver's own **curve** for a `gpio`
or `esp32_temp` input; the daemon's **live** duty (a host curve's output, pushed on the 0.5 s
rule tick when it changes and refreshed every 5 s, never persisted); and the
**fallback**. With the power switch configured, "host powers on" means *its*
power-on event — the button press asserting PS_ON# — confirmed by the sense
wire reading the rail up, so a reset of the receiver itself (a crash, a
reflash, a daemon reconnect) never re-fires the boost. Without the power
switch, USB host presence stands in (debounced 3 s so a bus reset doesn't
re-fire it), else the boost fires once at receiver boot. Each fan's window is
its own `boost_seconds` long; no boost (or `boost_seconds: 0`) sits it out. A
boost is the receiver's, run before the daemon exists, so a host output has
none (the key is refused there).

**The fallback is a slider on the phone**, on every fan's card, and the
**output and input are pickers** in the card's editor; all of them write to
wherever the value lives. While a daemon is connected, to the daemon: into the
config file like every other edit, and the daemon pushes the standalone values
to the receiver. **With no daemon at all**, straight to the receiver (a control
op over BLE, nothing relayed to a host), stored in its flash so it survives
power cycles — and the pickers then offer just what a receiver runs by itself:
its headers and pins, and the `fallback`, `gpio:N` and `esp32_temp`
inputs. So the receiver is a fan controller on its own: every fan on it runs
its fallback or its own curve, the boost still primes a pump at power-on, and the phone dials, adds,
moves and removes them. That is the bench case (a carrier board, a PSU and
fans, no BC-250 booting) and the machine-off case too — dial the fans down at
night without waking anything. What the receiver can't do alone is a *host*
curve: it has none of the host's temperatures to read, so a `temp` or load fan
runs its fallback until a daemon connects. There is one source of truth, and it is the
config: a daemon connecting pushes the file's list over whatever the receiver
held — every output, `fallback`, `boost`, input kind and receiver curve — so a
fan dialled standalone lasts exactly until then, and the phone writes into the
file whenever a daemon is there.

**`hysteresis`**, **`ramp`** and **`boost_seconds`** are each fan's own, with
a default where the fan says nothing (3 °C, 5 %/s, 5 s): a board header
mirrored over `gpio:N` or `chip:pwmN` is already smoothed by the board's
firmware and wants `ramp: 0`, while the temperature curve next to it wants the
ramp — so each says for itself. Each applies to some fans only and is refused
on the rest, so a key that would silently do nothing is a startup error
instead: `hysteresis` to a temperature input (`temp`, `chip:label`, `pmbus:`,
`smu:`, `file:`), `ramp` to any input with a curve, `boost_seconds` to a fan
with a `boost`. The receiver runs `ramp` and `boost_seconds` itself (rounded
to whole units); `hysteresis` is the daemon's, since only its curves read a
temperature.

**The old shape is refused.** Until Sep 2026 the block was an object of
`header1`..`header6` blocks with a `source`; the daemon (and `led --check`)
now refuse it with the converted list printed, ready to paste over the old
block — `source` became `input`, each header's number became its `output`,
and the old `pins` override became `gpio:N` outputs. The `constant` input is
refused with a line saying it became `fallback`.

### Host outputs

A fan whose `output` is `chip:pwmN` is driven by the daemon writing the
host's own hwmon pwm output — the BC-250's fan header on the NCT6686D
(`fan2`/`pwm2` is the main fan header per the BC-250 docs; `--fan-status` and
the phone's picker show every output with the rpm of the tachometer beside
it, which tells the wired one). It works the way CoolerControl and lm-sensors'
`fancontrol` do: `pwmN_enable = 1` takes the output over (manual), `pwmN` is
the duty (0..255), and the value `pwmN_enable` held before (2 on the nct6687
driver: the board's own curve) is what hands it back.

It needs a driver that can *set* the output: the out-of-tree
[nct6687d](https://github.com/Fred78290/nct6687d) (`force=1`) can; the
in-kernel `nct6683` is read-only — the daemon then says so once, leaves the
output to the board, and the phone's card reads "read-only". Only one program
may drive an output: stop CoolerControl or `fancontrol` for the outputs the
config names (the daemon notices a pwm value it didn't write and says so).

Switching between the board and the host is the output, from the phone or the
file: a host output no fan names is the board's — park the fan (`"output": ""`)
to hand it back, and make the header its input to keep watching it there. A host output's `fallback` is what it runs while its input
can't be read; it has no `boost`.

**The board always gets its output back.** Every write to a `pwmN_enable`
goes through one place (`daemon/pwmout.hpp`), and:

- before an output is taken over, its name, its path and the `pwmN_enable` and
  `pwmN` values found are written to a claims record under the state dir
  (`/var/lib/led-controller/pwm-claims`, systemd's `StateDirectory`) and
  synced to disk — no record, no takeover;
- it is handed back — `pwmN` restored first, then `pwmN_enable`, read back to
  check (lm-sensors' `fancontrol` order) — whenever no fan drives it any more
  (an edit, a reload, a fan deleted), and on every exit the daemon runs code
  for; one that won't go back is set to full speed instead
  (`pwmN_enable = 0`, then manual at 255), never left at a low duty;
- `ExecStopPost=/usr/local/bin/led --release-fans` hands back whatever the
  record still holds after **any** stop — a crash, `kill -9`, the watchdog —
  and a starting daemon does the same before it claims anything;
- `WatchdogSec=30`: the main loop pings systemd, and a hung daemon is killed
  (then `ExecStopPost` runs), so a fan can't freeze at its last duty;
- a hwmon driver reloaded while an output is driven comes back under another
  `hwmonN` with the chip still in manual mode: the claim follows the output by
  name, so the values restored are the board's, never the daemon's own;
- every 5 s the output is read back: a `pwmN_enable` something else reset (a
  resume from suspend) is taken back, and the journal says so;
- a lock in the state dir keeps a second daemon (a `./led cfg aurora` beside
  the service) from touching the outputs; `--fan-status` and `--check` never
  do.

```sh
sudo led --release-fans                        # hand everything back by hand (a no-op while a daemon holds them)
cat /var/lib/led-controller/pwm-claims         # what is taken over right now (absent: nothing)
```

### VRM and GDDR6 temperatures

The BC-250's two voltage regulators (the CPU rail and the GPU rail) sit on
one PMBus controller at I2C address `0x60`, and each reports its own
temperature — the part of the board that gets hottest under load and that no
hwmon driver sees. The daemon reads them itself, no other service needed, as
`pmbus:CPU VRM` and `pmbus:GPU VRM`: a fan `input`, a `sensors` candidate for
the LED temp rules, and two rows in the phone's picker.

The bus has to be brought out first. `I2C_HEADER1` (3 pins: SDA, SCL, GND)
carries nothing on its own; the live SMBus is on the `TPMS1` debug header. Two
jumper wires bridge them: `I2C_HEADER1` **SCL → TPMS1 pin 4** (`SMB_CLK_MAIN`)
and **SDA → TPMS1 pin 6** (`SMB_DATA_MAIN`), no ground wire needed. The pinout
photos in [BC250-Telemetry's hardware guide](https://github.com/onlinermm/BC250-Telemetry/blob/main/hardware.md)
show exactly which pins; that project also worked out the controller's
register formats, which the daemon's reads follow. The kernel's `i2c-dev`
module is what makes the buses appear as `/dev/i2c-*`; `make install` lists
it for every boot (`/etc/modules-load.d/led-controller.conf`) and loads it
right away, so the wires are the only step. To see the bus yourself:

```bash
sudo i2cdetect -l                                            # the buses
sudo i2cdetect -y 4                                          # 60 should answer (usually bus 4)
```

The daemon finds the bus on its own: it probes every `/dev/i2c-N` for a device
at `0x60` whose output-voltage register reads sensibly (a read only — it writes
nothing to a bus that hasn't answered), logs `pmbus: VRM controller at 0x60 on
/dev/i2c-4`, and reads both rails every half second on a thread of its own
while a fan, a rule or a watching phone wants them. The rails are read only
while wanted, and a controller that stops answering (the wires came off) is
dropped and searched for again, the fan on its `fallback` meanwhile like
any lost sensor. If nothing answers on any bus, `--fan-status` shows the
input as `(not found)` and the daemon keeps looking every 30 s.

While a phone watches, the same controller's rail voltages and currents and
its 12 V input are read too, for the **Host power** card on the Power tab
([The dashboard](#the-dashboard)); nothing reads them otherwise.

The eight GDDR6 chips are a harder case. Nothing in the kernel reads them: the
value lives behind the SMU (the GPU's management microcontroller), which has no
stock command that returns it. The way around it — worked out by
[pan-Rijovich/bc250-memory-temperature](https://github.com/pan-Rijovich/bc250-memory-temperature)
and packaged by [BC250-Telemetry](https://github.com/onlinermm/BC250-Telemetry),
both MIT — is to upload a small program into the SMU and point an unused command
slot at it; that program then asks the memory controller for each chip. The
daemon does this itself, exposing the chips as `smu:` sources — no setting to
turn on; it works wherever it can and touches nothing where it can't:

```jsonc
"input": "smu:VRAM hotspot"     // the hottest chip
"input": "smu:VRAM average"     // the mean of the eight
"input": "smu:VRAM 3"           // one named chip, 0..7
```

```jsonc
"vram_temps_interval_ms": 1000  // optional, top level: how often to re-read (default 2000, floored at 250)
```

- **Nothing is opened until something asks** for an `smu:` reading — a fan's
  input, a rule, or the phone's sensor picker.
- **The `bc250_memory` kernel driver, when loaded, does the reading** (see
  below); the daemon then never commands the SMU.
- **Otherwise the SMU's secure-access gate must already be open**, done by a
  patched BIOS such as [RescueMei's DXEv3 build](https://github.com/RescueMei/BC250-DXEv3-BIOSMOD).
  The daemon does **not** run the unlock itself — that is an exploit, the risky
  half, and it belongs in firmware that runs once at boot. If the gate is
  closed the daemon says so once and offers no readings.

The default 2 s is well inside how fast a GDDR6 package heats (its thermal
time constant is tens of seconds), eight SMU commands every 2 s are nothing
next to a GPU governor sharing the window, and the kernel driver caches its
readings for 1 s, so reading faster gains nothing there.

The daemon also checks the board is a BC-250 on stock **P3.0** firmware (the
build the uploaded program was compiled against) and reads its own upload back
before trusting it. The patch lives in the SMU's RAM only and is gone on the
next reboot; the daemon re-applies it when asked. On anything that is not a
BC-250 the check fails before the SMU is opened, and the sources simply never
read. Code 80 is the sensor's
ceiling and reads as 120 °C, meaning "at least that" — set a VRAM curve's top
below 120. `--fan-status` prints whether the patch took and, if not, why (a
locked SMU, the wrong board or BIOS); the daemon logs the same to the journal.

**Running alongside a GPU governor.** The SMU is reached through one shared
register window (`0xB8`/`0xBC` on `00:00.0`), and an SMU GPU governor such as
[filippor/cyan-skillfish-governor](https://github.com/filippor/cyan-skillfish-governor)
(smu branch) drives the same window. That governor takes `flock` on the PCI
config file around its accesses, and the daemon takes the **same** lock around
each of its own, so the two coordinate rather than corrupt each other's
transactions. This makes concurrent use safe in the ordinary case. It is not a
hard guarantee — the governor locks per register access rather than per
address+data pair, so a residual race on its own writes remains — so keep the
read cadence modest (the 3 s default is fine; there is little reason to poll
VRAM temperatures fast) and, if you can, run only one SMU tool. A reader that
does **not** take the lock (BC250-Telemetry's own memory service) must not run
with the governor at all.

> **Risk.** The uploaded program waits on the memory controller with no timeout
> of its own, and this integration has not been validated on hardware. A wedged
> SMU may need a full power-off (standby included) to recover.

If you would rather not have the daemon touch the SMU, BC250-Telemetry's own
memory service publishes the same readings as millidegree files that the
`file:` input reads (`file:/run/bc250/memory_hotspot_temp`,
`memory_avg_temp`), and the picker lists any `/run/bc250/*_temp` file. The same
files exist for its VRM readings (`cpu_vrm_temp`, `gpu_vrm_temp`).

#### With the kernel drivers (`bc250_vrm`, `bc250_memory`)

The [linux-cachyos-bc250](https://github.com/mastag/linux-cachyos-bc250)
kernels ship two drivers for the same hardware,
[bc250_vrm](https://github.com/Hexxeh/bc250-vrm-dkms) (loaded on every
BC-250) and [bc250_memory](https://github.com/Hexxeh/bc250-memory-dkms)
(opt-in). Each talks to what the daemon would otherwise talk to itself, and
neither can share: `bc250_vrm` claims address `0x60`, so `i2c-dev` refuses
the daemon the bus, and `bc250_memory` drives the SMU's mailbox from the
kernel without the lock above, so two readers would garble each other's
commands. The daemon therefore steps aside for them, and no config changes:

- **`bc250_vrm` registered** → `pmbus:CPU VRM` / `pmbus:GPU VRM` (and the
  Host power card) are read from its hwmon files; the bus is never opened.
  A driver loaded after the daemon started takes over within 5 s, the bus
  released first. Without the wires the driver registers nothing and the
  daemon's own scan finds nothing either — same as before.
- **`bc250_memory` loaded** → `smu:` sources are read from its hwmon files,
  and the daemon sends the SMU **no** command — only one SMU client is safe. A
  module loaded while the daemon is reading the SMU itself is noticed
  before its next command. If the module is loaded but its probe failed (SMU
  locked), it has no sensors and the daemon still leaves the SMU alone,
  saying so in the journal and `--fan-status`.

The drivers' own names work as specs too and mean the same reading:
`bc250_vrm:CPU VRM Temp` is `pmbus:CPU VRM`, `bc250_memory:VRAM Chip 3` is
`smu:VRAM 3` — read on the source's own thread (a `bc250_vrm` sysfs read
sleeps ~5 ms in the kernel, which the render loop shouldn't wait on). The
phone's picker lists them once, under `pmbus` and `smu`. `--fan-status`
says which way each is read (`vrm: read through the bc250_vrm driver (...)`).
The hotspot and average are computed from the eight chips either way.

### Getting the block onto the receiver

Two consumers read the same block:

- **`make flash` / `make flash-source`** bake the standalone part — the
  board's header map, and per fan on a receiver output its output,
  `fallback`, `boost`, `boost_seconds`, `ramp`, the input kind and a `gpio`
  input's pin and curve — into the receiver's `fancfg` flash partition,
  exactly as `strip.pin` is baked. So a box that never runs the daemon is
  configured by editing the block and running `sudo make flash-fan` (the
  fancfg partition alone, a couple of seconds); its fans run their `fallback`
  duties and their gpio curves, because those are the receiver's own. Fans on
  host outputs are the daemon's and are only checked here. The config is
  `/etc/led-controller/config.json` when it exists, else the repo's
  (`CONFIG=path` overrides).
- **The daemon** reads the block at runtime, drives the curves, and pushes the
  same standalone part at startup (and after every edit), so an edit takes
  effect without a reflash. The receiver **persists that push in NVS**; a
  re-flashed fancfg with *different* values outranks a stale push (the same
  newer-default-wins rule as its saved baud), and `make clear-nvs` also
  reverts to the flashed values.

```sh
sudo make flash                        # firmware + the config's fans block, always
sudo make flash-fan                    # rewrite only the fans block: seconds
sudo make flash-fan CONFIG=other.json  # ...from a different config
led /etc/led-controller/config.json --fan-status   # what each fan resolves to right now
```

`--fan-status` prints every fan's output (the receiver slot, or the host's
pwm file) and input, the sysfs file (or `pmbus:` rail, or `file:` path) it
resolved to, its current reading and the duty it would run, plus the
catalogue of sensors and outputs as the phone's pickers see it (a `fallback`
or `gpio` fan on a receiver output is marked as the receiver's to run) — the
first thing to run when a fan isn't doing what the curve says, and whether
dashboard edits can be written back to the config. It never takes a host
output over.

### Editing fans from the phone

With the BLE remote on, the web page shows every fan live and lets you
redraw its curve, pick its output and input, set boost and fallback, change
its hysteresis, ramp and boost length — and **add and delete fans** — see the
dashboard under [BLE remote](#ble-remote). An edit travels phone → receiver →
daemon, which validates it exactly as it validates the config, applies it on
its next tick, and **writes it into the config file** —
`/etc/led-controller/config.json` on a deployed box. Only the bytes of the
`fans` block are replaced (re-printed in the file's own four-space style,
every key and fan in the order you wrote them); everything around it stays
byte for byte as it was, and the first rewrite of a daemon's run leaves the
file as it found it in `config.json.bak` beside it. So the config remains the
one place the box is described: back it up, move it to a new install, diff
it, and the phone's edits come along. The same file watch that reloads a hand
edit ([Live reload](#live-reload)) works the other way too: edit a curve in
the file, and the phone's dashboard shows the new curve a moment later.

Every edit names the list's revision as the phone saw it, so an edit made
against a list that has changed since (a second phone, a hand edit) is
refused rather than landing on the wrong fan; a refused edit comes back with
the reason, and the editor stays open. Names (up to 16 characters) are
editable too; a sensor or host output that isn't on the machine is refused
there and then (a hand edit in the file may name one that turns up later). A
sensor that stops reading while the daemon runs — a thermistor unplugged (the
chip then reports 0 °C), a driver unloaded — puts its fan on the fallback
speed, not on a curve fed a temperature nobody measured; the journal says so
once, the phone's row says "no reading", and the sensor is looked up again
until it is back. The dashboard is read-only when the daemon can't write its
config (the page hides the cogs); a write that fails mid-way is reported in
the journal and the edit runs until the next restart. The daemon takes edits
only from the receiver's link, which only the receiver's BLE service writes,
and that only with the flash-time token — the same trust the power button
has.

Wiring:

| output | receiver pin (ESP32-C3) | connects to |
|---|---|---|
| header1–header4 | GPIO5, 6, 7, 10 — the carrier board's FAN1–FAN4 | one fan's PWM input each (pin 4 on the 4-pin connector) |
| — | — | fan +12 V and GND come from the PSU, **sharing a common ground** with the receiver; tach (pin 3) unconnected |
| a `gpio:N` input | GPIO0, 20 or 21 — J11 pins 12, 8, 10, each with a GND beside it | a fan header's PWM (pin 4) and GND, two wires only — see `gpio:N` above |

The header → GPIO map is the board's, not the config's (`tools/pincheck.py`,
`FAN_PINS`; the plain ESP32 gets 16, 17, 18, 19, untested). A hand-wired
build on other pins, or with a fifth and sixth fan, names its pins as
outputs: `"output": "gpio:20"`. `tools/fancfg.py` validates the pins like the
power switch's encoder does — nonexistent on `TARGET`, flash/host-link pads,
input-only pads, a raw strap pin, collisions with `strip.pin`, the power
switch's pins (a warning from `flash-fan` alone, an error from `make flash`,
which writes both blocks), a header the board doesn't have, or each other —
and the receiver checks every pin again whenever one moves, refusing (and
logging) one it can't drive rather than driving it.

Two guardrails, mirroring the power switch's:

- **The chip must run a firmware that reads this block's layout** (the `FAN5`
  fancfg, from the fan list on; older blobs are not read) **and whose
  partition table has the `fancfg` entry** (v1.13.0 or newer). `make
  flash-fan` against an older layout writes a sector that firmware never
  reads — a silent no-op, except the receiver's debug log says `no fancfg
  partition` at boot — and a firmware that knows only an older layout reads
  the new blob as "no config" and turns the fans off. `make flash` writes both
  halves together, so only `flash-fan` alone can hit this: reflash the
  firmware first. The daemon, the firmware and the page moved together to
  the fan list: update all three (`make install`, `make flash`, the page).
- A full `make flash` / `make flash-source` rewrites fancfg from the config
  and **wipes the daemon's persisted push**, so the receiver runs exactly the
  flashed block until the daemon next starts. Which is the same block, so
  nothing changes unless the two copies of the config differ.

## BLE remote

With the power switch fitted, the receiver can also be the machine's *remote*
power button: it advertises a small Bluetooth LE service (idling on 5VSB even
while the machine is off), and a phone within radio range can press the
button — no WiFi, no app store, works wherever the machine is carried. The client is the Web Bluetooth page in `docs/` (host it on GitHub
Pages and "install" it from Chrome once; it works offline afterwards) — or
any BLE tool that can write a GATT characteristic. Web Bluetooth is a
Chrome/Edge-on-Android (and desktop) feature; Safari has none and WebKit has
said it won't add it. On an iPhone open the page in
[Bluefy](https://apps.apple.com/app/bluefy-web-ble-browser/id1492822055) (free;
WebBLE, paid, also works) — a browser app that ships its own Web Bluetooth
polyfill on top of CoreBluetooth. The page needs nothing beyond the standard
API, so it runs there unchanged; opened in Safari it offers the Bluefy link.

Like the other receiver features it is **standalone** (no daemon involved)
and configured in the config's `ble_remote` block, which `make flash` bakes
into its own 4 KB `blecfg` partition:

```jsonc
"ble_remote": { "enabled": true, "name": "BC250", "token": "5f3a9c1e2b7d" }
```

```sh
sudo make flash          # firmware + the block
sudo make flash-ble      # rewrite only the block: seconds (re-token, rename, disable)
```

`token` (8–16 characters, required when enabled; `openssl rand -hex 6` makes
a good one) is the shared secret the phone must present with every command —
the only thing standing between anyone within radio range and your power
button, so `tools/blecfg.py` refuses to write an enabled block without one.
Enter it once on the web page; it is remembered on the phone. It sits in the
config in the clear: anyone with a shell on the box can read it, and can also
just run `systemctl poweroff`, which is all it guards. `name` is the
advertised device name (public by definition).

Several machines: the page keeps every receiver the Bluetooth chooser has
ever granted and lists them on the Receiver tab (tap the receiver's name in
the header to get there), each marked on / booting / off / nearby / out of
range from its advertisements while the tab is open — pick one to switch (the
page holds one connection at a time, and reconnects to the last pick on its
own), "add a receiver" opens the chooser for a new board. Tokens
are remembered per receiver: a new board first tries the token you entered
first; if that board was flashed with a different one, its first command is
rejected and the page asks for that board's token. Give each board its own
`name` so the list reads as more than `BC250`, `BC250 (2)`.

What the remote can *do* to the machine is deliberately narrow — the same
gestures as the physical button, and nothing else (the fan dashboard below
edits the daemon's curves, never the power):

- **Power on** (the press-while-off edge, `pwr::remoteRequest`), taking the
  exact same path as a real press: the fan boost arms, the power-on
  animation replays, the sense wire confirms the boot.
- **Graceful shutdown** (the short press): asks the host over the link to run
  its poweroff command — needs `power_switch.short_press` set in the daemon
  config, like the button.
- **Force off** (the hold): release PS_ON# and cut the PSU immediately — the
  crash rescue, which is the one moment a *remote* power button really earns
  its keep. The page asks twice (the sheet, then a confirmation); the
  firmware accepts it while booting too (a boot that never comes up is exactly a case for it).

### The dashboard

The page is four tabs, each fitting a phone screen; the tabs, the editors
and the shutdown sheet are history entries, so the phone's back gesture
steps out of them the way a native app does. A sticky header on every tab
names the receiver (a tap opens the Receiver tab), shows the PSU
state, and — while the daemon reports — the host's readings: CPU
temperature (the top-level `sensors` pick), CPU load and GPU load.

- **Power** — the ring alone, centred where a thumb reaches. Its color is
  the PSU state and its label the one thing a tap does: connect, power on,
  or (while on) open the sheet with **Shut down** and **Force off**. Under
  it, while the machine is on and its VRM controller answers ([VRM and GDDR6
  temperatures](#vrm-and-gddr6-temperatures)), the **Host power** card: per
  rail (CPU, GPU) the volts, amps, watts and VRM °C, the 12 V input, and the
  two rails' draw together in its title. A cog
  in the corner opens the **power switch's settings**: the sense wire's two
  thresholds as sliders under its live reading in millivolts (read it with
  the machine on and off, put the values well apart between the two), the
  boot timeout, the hold-to-force-off time, and — while the machine is on —
  the **short press** switch (whether a press asks the machine to shut
  down; the same `short_press` setting the sheet's Shut down uses), and the
  **wake input**: the pin an OpenPuck's power-on pulse arrives on, picked
  from the receiver's free input pins (the same list a `gpio:N` fan input
  offers, less the pins fans read on) or set to none — the one pin a
  phone may move, since a pulse there can only ever power the machine on.
  The rest of the wiring is listed, read-only: those pins are set when
  flashing. **Save** goes to the daemon while the machine is up (into the
  config's `power_switch` block — the wake pin into `pins.wake` — then
  pushed to the receiver — `saved` means the config came back) and straight
  to the receiver otherwise, where it is stored until a daemon next connects
  and the config wins again; the editor says which. The receiver checks a
  wake pin against its own facts (another feature's pin, a flash, strap or
  link pin) and refuses one it can't use, keeping the pin it had — the page
  compares the two views a few seconds after a routed save and says so; a
  daemon from before the setting never pushes a wake pin, so the card then
  says the pin is kept on the receiver alone. A receiver on firmware from before the
  settings shows no cog.
- **Fans** — one row per fan, in the config's order: its name, its output
  and what it follows with that input's current reading (`Header 2 · CPU
  temperature · 58.3 °C`, `nct6686 pwm2 · Board curve`), and the duty
  actually applied. A chip appears only when the fan is *not* doing what it
  is set up to do, and the row then says what it runs instead: `boost` for
  the power-on boost, `fallback` when nothing is driving it (the host off,
  the daemon not yet up), `hold` while the host powers down and the last
  live speed is kept, and for a host output `read-only`, `no output` or `not
  driven` when the daemon can't drive it. Tapping a row shows its curve with
  the operating point marked; the cog opens the fan's editor: name,
  **Output** (the receiver's headers and free pins, the host's pwm outputs
  a driver can set — each with its duty and the rpm of the matching tach —
  or none; an output another fan has is listed with that fan's name and
  can't be picked), **Follows** (every input kind in the [Fans](#fans)
  table that fits the output, each with its live reading beside it so the
  pick is made on the numbers — then every labelled hwmon temperature and
  every board pwm output the machine has, by name, from the catalogue the
  daemon sends while a phone watches; picking one fills the `chip:label`
  spec, and an "Other sensor…" row keeps the typed field for one that isn't
  present right now; on a host output, **Board curve** hands it back to the
  board; a machine with more sensors than fit the receiver's 2 KB loses pwm
  outputs first, then temperatures from the end, never one a fan follows,
  and the row says how many are missing; a pin list for `gpio`), the curve
  (drag the points or type them; add and remove up to eight) with its
  **ramp** and, for a temperature input, its **hysteresis**, the **fallback
  speed** and, on a receiver output, the power-on **boost** with its length.
  A number box keeps what is typed while it has focus — emptying it to type
  another value is safe — and falls back to the stored value when left
  empty. **Save** sends that fan and the row says `saved` only when the
  daemon has applied it, written it into the config and pushed the config
  back; a refusal is said in the status line and the editor stays open — see
  [Editing fans from the phone](#editing-fans-from-the-phone). **add a fan**
  under the list opens the same editor on a new fan (on the first free
  header, or no output), and the editor's **Delete** removes one. A fan on a
  receiver output the receiver isn't driving (a pin it refused) says so on
  its row. With no daemon at all the rows come from the receiver's own
  stored slots: Output then offers its headers and pins, Follows `fallback`
  and `gpio` — what a receiver runs alone — and Save (or Delete, or add a
  fan in a free slot) stores it on the receiver until a daemon next connects
  and the config wins again. A receiver on firmware from before the fan list
  shows a note to update it (and the daemon) instead of the rows.
- **LEDs** — the config's `strip` block, no Save: a slider applies on
  release, a switch on the tap — the daemon corrects the live strip on its
  next frame and writes the value into the config, and the card says
  `saved` when the config comes back. **Scenes** first: every rule whose
  condition is a bare `file:` path, as a switch the daemon flips by creating
  or removing that file (nothing is written to the config for a toggle —
  the rule reacts on its next tick, like a shell's `touch`); a scene whose
  settings have a `color` gets a color picker, one with a `level` a slider,
  both written into that rule. Then **Brightness**, **White** — a swatch of
  what the strip will show (the first scene carrying a color, at its level,
  run through gamma, white balance and brightness in the daemon's order),
  the balance as one slider per channel, gamma per channel — and
  **Direction** (the `reverse` switch). This is the white-balance tuning
  flow, see [Tuning the colors](#tuning-the-colors). A receiver on firmware
  from before the strip view shows the tab empty.
- **Receiver** — the boards this phone knows (tap to switch; "add a
  receiver" opens the chooser), and for the current one its firmware
  version, uptime, free memory, whether a host is on the link, plus
  **Change token** and **Forget**.

The page is Preact with htm, vendored into `docs/vendor/` so there is no
build step and nothing loads from a CDN (`docs/ble.js` is the link and the
protocol, `docs/app.js` the screens). Every file is precached by the
service worker: bump its `VERSION` when any of them changes, or installed
phones keep serving the old one.

Nothing about the dashboard costs anything while no phone has it open: the
receiver only assembles its view while a page is subscribed, and only then
tells the daemon to read and send the readings (a keepalive every 10 s; the
daemon stops 30 s after the last). A receiver on firmware from before the
dashboard shows the Power tab alone. Open `docs/index.html?demo` (or the hosted
page with `?demo`; `&tab=fans`, `&tab=leds`, `&nodaemon` for the machine-off
view) to see the dashboard on sample data with no receiver at all.

Radio policy: the receiver advertises in both PSU states — a crashed machine
must be reachable, and it counts as "on" — every 300 ms in either state:
opening the page waits for two advertisements (seeing the receiver, then
connecting to it), so the interval is most of the time to connect, and
300 ms is still gentle on 5VSB. Once a phone connects, the receiver asks it
for a 15 ms connection interval (phones pick 30–50 ms on their own): every
step of loading the dashboard is a request and an answer, one at a time, each
waiting for the next exchange, so a shorter interval loads it about three
times faster. A phone may decline; `debug_log` shows the interval it settled
on. The strip's bitstream leaves the chip by SPI
with DMA (`render.cpp`) for exactly this coexistence: the earlier RMT path refilled its buffer from an
interrupt, and the BLE controller's interrupts delayed that refill enough to
tear bits — random LEDs flickering while a phone was connected. The RMT path
is still there should a board ever need it: `make flash-source STRIP_USE_RMT=1`.

The advertisement also carries the host's state (manufacturer data under the
unregistered id 0xFFFF: a version byte, then 0 off / 1 booting / 2 on), so the
page's Receiver tab can show which boards are nearby and which are on without
connecting to each. Chrome only hands a page that data for a receiver granted
with it asked for: a receiver added before this page version shows as nearby
only until it is added again (Receiver tab → add a receiver, pick the same
board).

Guardrails, mirroring the fans': the chip must run a firmware whose partition
table has the `blecfg` entry — `make flash-ble` against an older layout is a
silent no-op except for the receiver's debug log saying `no blecfg partition`
at boot. A config with no `ble_remote` block writes the remote off.

The power switch is optional. On a receiver without one (`power_switch`
absent or off — a plain ESP32 on a desk, say) the remote still advertises and
serves the Fans, LEDs and Receiver tabs; the Power tab says there is no
switch, the receiver refuses the power commands, and the header's on/off is
whether the daemon is streaming to it rather than the PSU's state.

## Previewing without hardware

Frames go to a list of *sinks* — the serial transport and/or an on-screen
viewer — so the daemon runs with no strip attached. Set `LED_PORT=none` (or
`serial.port` empty) to skip serial:

```sh
make virtual-strip
./virtual-strip                          # on-screen strip; waits for frames
LED_PORT=none led config.json aurora     # renders into the viewer, no device
```

The viewer shows the exact bytes the strip would (already gamma/white-balance/
brightness corrected). Drop `LED_PORT=none` to drive a real strip and preview
at once.

## The daemon

```sh
make                     # build ./led
sudo make install        # /usr/local/bin/led + systemd unit + default config
sudo make uninstall      # remove everything, including the config
```

`make install` never overwrites an existing config, checks the deployed one
against the new build first (see [Checking a config](#checking-a-config)),
restarts the service if
it's running (so a rebuilt daemon goes live immediately), and adds your user
to the serial port's group (effective next login) so `led` can run
unprivileged for testing. The unit restarts on serial failure every 2 s, so unplugging the
adapter heals itself.

```
led <config>            run the rules
led <config> <effect>   run a single effect forever (testing)
led --list              list available effects
led --check <config>    validate a config without running it
```

### Adding an effect

Drop a file in `daemon/effects/` — it's compiled in and self-registers. Effects
render against the host `Strip`; the receiver just replays what's streamed. Pure
animations (no host data) can also be a boot/shutdown slot; data-driven ones
(`load`) can't.

```cpp
#include "effect.hpp"

class MyEffect : public Effect {
public:
    void init(const EffectConfig& cfg, int leds) override { ... }
    void render(Strip& strip, float t) override { ... }
};

REGISTER_EFFECT("my_effect", MyEffect)
```

## Wire protocol

Pixel frame, host → receiver:

| bytes | content |
|---|---|
| 2 | sync `0xAA 0x55` |
| 1 | GPIO pin |
| 2 | LED count (LE) |
| 3·n | RGB, one triple per LED |
| 1 | checksum: XOR of pin, count, and RGB bytes |

Command frame (distinct second sync byte, so the pixel parser skips it):

| bytes | content |
|---|---|
| 2 | sync `0xAA 0x56` |
| 1 | command (`0x01` shutdown, `0x02`–`0x04` recording upload) |
| 2 | payload length (LE) |
| n | payload |
| 1 | checksum: XOR of command, length, and payload bytes |

Receiver → host, three frame types on the same line, each with its own second
sync byte: a **log** frame (`0xAA 0x58`, the debug backchannel), a **request**
frame (`0xAA 0x59`, the power button asking for a graceful shutdown; answered
with command `0x06`), and a **message** frame (`0xAA 0x5A`) for the BLE
dashboard — `kind(1) len(2, LE) payload checksum`, up to 512 bytes, sent
once, carrying "a phone is watching" (`0x02`) or a phone's edit of one of the
daemon's views (`0x05`: the view's id, then the edit). The dashboard's host →
receiver command is `0x12`, one **view**: its id, then its JSON text — the fan
list as the daemon runs it (`0`), its live readings (`1`), the strip settings
and scenes (`2`), the sensor catalogue (`3`: every hwmon temperature and pwm
output a fan could follow or drive, with readings, every 5 s while a phone
watches) and the power switch's tunings and short-press command (`4`), in the
shapes `daemon/fans.hpp`, `daemon/strip_remote.hpp` and
`daemon/power_remote.hpp` document, up to 2 KB each (`protocol.hpp`
`VIEW_MAX`; the receiver takes any command up to that whatever its strip
length). The receiver keeps the last view of each id and relays it to the
phone without parsing it — so a new daemon view needs no firmware change —
and the phone reads one longer than a notification in pages. The fans' standalone settings (`0x11`: six 25-byte slot records,
each with its output), the power switch's tunings (`0x0E`: hold, boot timeout
and the two sense thresholds, four little-endian u16s) and its wake pin
(`0x10`: one GPIO byte, `0xFF` = none) are binary, because the receiver does
read those: they are what it runs on its own.

Byte values and payload formats live in `common/protocol.hpp`, shared by host
and firmware. The receiver drops bad-checksum frames and rescans for sync, so a
desync recovers within a frame; if nothing valid arrives for
`host_timeout_ms`, it blanks the strip. **Host and receiver must be updated
together when the protocol changes.**

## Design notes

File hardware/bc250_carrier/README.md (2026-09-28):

# BC-250 carrier board (rev D)

An 80 × 34.5 mm two-layer carrier for the ESP32-C3 Super Mini that runs the
receiver firmware in the BC-250. It replaces the loose wiring for the
[power switch](../../README.md#power-switch), the WS2812B strip and the
[fans](../../README.md#fans) with one board: the Super Mini plugs into two
sockets on it, the PSU's own 10-pin Mini-Fit Jr plug goes straight onto a
right-angle header and lies flat over the board, the strip leaves through a
10 A JST-VH, and the illuminated power button plugs into a 4-pin JST-XH. A
2 × 6 pin header along the left edge (J11) takes the sense wire and breaks
out the module's five spare GPIOs, each beside a ground pin; the three
rails have a 2 × 3 header of their own (J14) in the top left corner above
it, a row apart, so the rails and the GPIOs never share a header.

A second layout of the same board, **[rev E](../bc250_carrier_e/README.md)**,
puts every connector left of the PSU header, the PSU header at the
right-hand end and the module right beside it, with the four fans stacked
down the left edge (75.8 × 34.5 mm). Same parts, nets and firmware; pick
either.

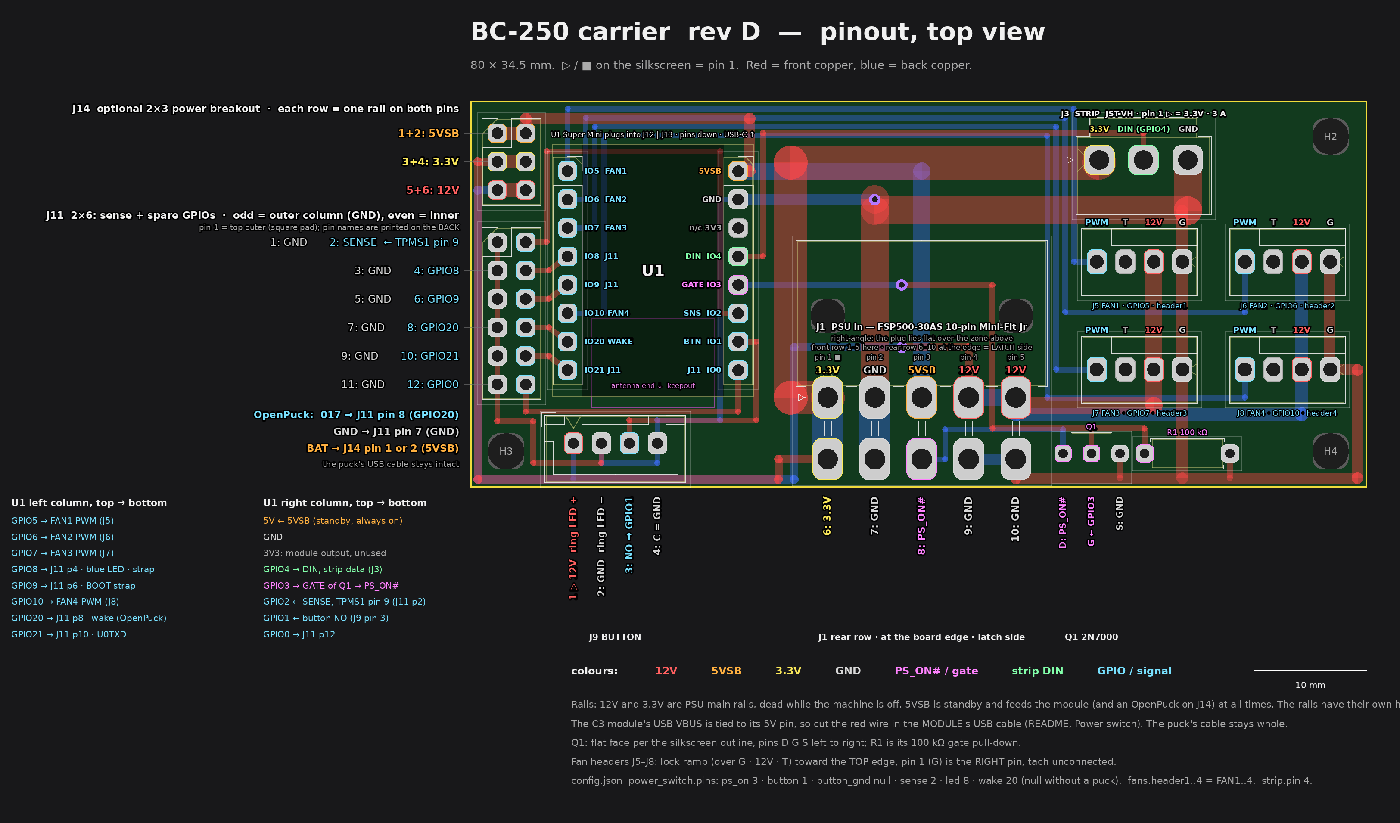
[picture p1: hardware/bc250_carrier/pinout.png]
Annotated pinout of the carrier: every pad labelled with its rail, GPIO and role, connector orientation, the OpenPuck wake hookup on J11


*The wiring diagram (`make pinout` → `pinout.png`, drawn from `generate.py`'s
geometry so it cannot drift from the board): top view, every pad labelled
with what it carries, pin 1 marks, connector orientation, and the OpenPuck
hookup on J11. Open the image at full size for soldering.*

The only discrete parts are the power switch's 2N7000 and its 100 kΩ gate
pull-down, exactly the circuit the README describes. No regulator (the Super
Mini has one), no level shifter (the strip reads 3.3 V data fine), no
capacitors or series resistors — the wired-up prototype works without them.

`make` regenerates the KiCad files, checks them (the geometry checker, then
KiCad's own DRC through its Python module), renders `out/preview.png` and
exports the board to `out/zoom-top.pdf` / `out/zoom-bottom.pdf`, the
schematic to `out/schematic.pdf`, the BOM to `out/bom.xml`; gerbers and
drill files land in `out/gerbers/`, and `fab.py` turns them plus the parts
list into one order-ready folder per fab under `out/fab/` (JLCPCB, PCBWay:
gerber zip, BOM, pick-and-place; see Ordering).

## Layout

Three columns, left to right:

- **The Super Mini**, USB-C at the top edge, with the button connector and
  the sense and GPIO header (J11) along the board's left edge and the power
  header (J14) above it in the top left corner.
- **The PSU header** on the bottom edge, a right-angle Mini-Fit Jr whose
  mating face points *up* the board. The PSU plug slides on from above and
  lies flat over the middle of the board; its wires leave over the top edge.
  So the board takes no extra room in the cable's direction: the plug and
  the first stretch of cable sit inside the board's own footprint. The whole
  column above the header is the **plug zone** — tracks only, nothing taller
  than the solder mask, because the plug body rides about 1.3 mm above the
  board and the wires drape over the rest. Keep it that way if you edit.
- **The strip VH** at the top right, the four fan headers as a 2 × 2 block
  under it, the MOSFET and its resistor along the bottom edge. A PC fan plug
  body is 12.7 × 5.8 mm (the Molex header itself is 10.4 × 6.0), so the block
  is spaced for the plugs: columns 13.2 mm apart, rows 9.6 mm apart (3.8 mm
  between the plugs). The headers' friction ramps face up the board, toward
  the strip connector, on all four; the silkscreen draws each ramp over its
  three pins (G, 12V, T) so the plug's latch side is obvious.

Rev B was 80 × 55 mm with a vertical PSU header on the right edge; rev C is
37 % smaller in area and the PSU cable no longer sticks out of the side.

Rev D is rev C made for hand soldering, after a board whose PSU stuck on (a
solder bridge in Q1's 1.27 mm footprint put PS_ON# onto GPIO3):

- **0.5 mm from every solder pad** to copper of any other net (rev C: 0.2),
  0.3 mm track to track. Q1 is on the wide TO-92 footprint.
- **The back is where every joint is made, so 12 V never runs past a pad of
  5VSB, GATE or a GPIO there.** The button LED's 12 V left the PSU
  header's row gap altogether (it now runs above the front row, over 1 mm
  from every header pad), GATE moved to the front (under the header's
  housing) and PS_ON# to the back: a bridge on the back can now only switch
  or trip the PSU, never feed 12 V into the module.
- **Rails and GPIOs on separate headers**: J11 carries the sense wire and
  the spare GPIOs, each with a GND beside it; J14, above it with an empty
  row between, carries 5VSB, 3.3V and 12 V (two pins each, top to bottom;
  12 V's row is 4.6 mm, pin centre to pin centre, above J11's SENSE/GND
  row, where rev C had them 2.54 mm apart). No rail track runs beside the module
  socket's pins any more: 3.3V and 12 V come up the left edge past J11's
  GND pins only, one per layer, and 12 V has the back to itself there.
- **Three mounting holes**: the top left one (H1) is gone, its corner is
  J14's. H2, H3 and H4 keep their places and names.
- **The sense wire goes on J11** (pin 2, GND beside it) instead of a lone
  pin.
- **A ground fill on both layers**, stitched with ground vias (see below).

## The PSU header

J1 is a Molex Mini-Fit Jr 5569-10A2 (39-30-0100; the DLL-5569-10AW clone on
the parts list), the 2 × 5 right-angle header that the FSP500-30AS's own
10-pin plug mates with. It sits with its two pin rows along the board's
bottom edge: the **rear row** (pins 6–10) right at the edge, the **front
row** (pins 1–5) 5.5 mm further in, pin 1/6 at the left. The footprint is
KiCad's Molex one, checked against the DLL datasheet (Sep 2026): same 4.2 mm
pitch, 5.5 mm row spacing and 1.8 mm holes, and the 3 mm peg holes are where
DLL's pegged variant (DLL-5569-10AWS) puts them. The part LCSC sells is the
AW without pegs, so those two holes stay empty — it solders fine without
them. One difference: the DLL body ends 3.5 mm in front of the front pin
row where Molex's ends 1.1 mm, so the mating face sits 2.4 mm further up the
board (at about y = 110 on the drawings) and the plug overhangs the top edge
by that much more.

The pin map comes from the PSU's pinout drawing (`fsp500-30as.webp`, "looking
into the front face of the connector", latch up):

| plug row (face view, latch up) | left → right |
|---|---|
| latch side | 3.3 V, GND, PS_ON, GND, GND |
| other side | 3.3 V, GND, 5V STBY, +12 V, +12 V |

In a right-angle Mini-Fit Jr the rear pin row feeds the upper contact row and
the latch ramp is on top, away from the board, so pins 6–10 are the latch
row (the same rows the vertical 5566 footprint has — KiCad draws its ramp on
the 6–10 row). Looking into the header's face from the top edge of the board,
+x is on your left, so the header face reads 5 4 3 2 1 over 10 9 8 7 6 and
the plug face is its mirror image: 1 2 3 4 5 on the lower row, 6 7 8 9 10 on
the latch row, left to right. Lined up with the drawing that gives `MF_NET`:

| header row | pins, left to right on the board |
|---|---|
| front row (pins 1–5, pin 1 is the square pad) | 3.3V, GND, 5VSB, +12 V, +12 V |
| rear / edge row (pins 6–10, latch side) | 3.3V, GND, PS_ON#, GND, GND |

The silkscreen prints the **edge row's** names in the 1.8 mm gap between the
rows on the front of the board and the **front row's** names in the same gap
on the back (there is no room anywhere else once the housing is on). Before
soldering the header, hold the PSU plug against it the way it will mate
(latch up) and confirm the 3.3 V pair lands on the left — the drawing is the
only source for this map, and the 5569's row numbering was derived, not
measured. If it turns out mirrored, the fix is one line in `MF_NET`.

## What is on it

| ref | part | footprint |
|---|---|---|
| U1 | ESP32-C3 Super Mini | not soldered: plugs into J12 + J13, pins down, USB-C at the board edge |
| J12, J13 | Super Mini sockets, left and right column | 1 × 8 female header, 2.54 mm, 5.7 mm low profile (ShouHan PM2.54-1x8PZZ-H5.7), 15.24 mm apart |
| Q1 | 2N7000 N-MOSFET | TO-92, wide: 2.54 mm between the legs (bend them out) |
| R1 | 100 kΩ | axial, 7.62 mm pitch |
| J1 | PSU in: 3.3V, 5VSB, PS_ON#, +12 V, GND | Molex Mini-Fit Jr 5569-10A2, 2 × 5 right-angle header with pegs (takes the PSU's 10-pin plug) |
| J3 | strip out: 3.3V, DIN, GND | JST-VH B3P-VH, 3.96 mm, 10 A contacts |
| J9 | power button: 12V, GND (ring LED), NO, C (switch) | JST-XH 4-pin (B4B-XH-A) |
| J11 | SENSE (TPMS1 pin 9 → GPIO2), then GPIO8, GPIO9, GPIO20, GPIO21, GPIO0, each with a GND beside it | 2 × 6 2.54 mm pin header, cut from a 2 × 8 (or solder the sense wire straight into pin 2) |
| J14 | optional: 5VSB, 3.3V, 12 V, two pins each | 2 × 3 2.54 mm pin header, cut from a 2 × 8 |
| J5–J8 | four 4-pin PWM fan headers | Molex 47053-1000, the KK 254 4-circuit header the 4-wire PC fan spec names: friction-lock ramp over circuits 1–3 only, so the fan plug's latch wall clears it (KiCad's Molex KK-254 footprint) |
| H2–H4 | M3 mounting holes (three: top right, bottom left, bottom right) | 3.2 mm, 73.6 × 28.1 mm spacing; rev C's top left H1 is gone, so a case standoff there must go too |

Matching housings: VHR-3N with SVH-21T-P1.1 crimps for the strip (20 AWG
wire for 3 A); XHP-4 with SXH-001T-P0.6 for the button.

## Wiring

| connector | pin | goes to |
|---|---|---|
| PSU J1 | see the table above | the FSP500-30AS 10-pin plug, straight on |
| STRIP J3 | 1 `3.3V`, 2 `DIN`, 3 `GND` | the WS2812B strip. 3.3V is the PSU's 3.3 V rail straight through; DIN is GPIO4 |
| BUTTON J9 | 1 `12V`, 2 `GND`, 3 `NO`, 4 `C` | the illuminated button: 1–2 feed its ring LED (a 12 V LED, i.e. one with its own resistor — the pins are the raw 12 V rail), 3–4 are the switch: `NO` → GPIO1, `C` is a **real ground**. Use the normally-open terminal: the firmware sees a press as the contact closing, and the NC terminal makes the PSU click on and off (Jul 2026) |
| SENSE, J11 pin 2 | `SENSE` | BC-250 TPMS1 pin 9 (the main 3.3 V rail) → GPIO2. One wire does it (the ground is shared through the PSU); pin 1 beside it is a GND if you want a two-wire plug |
| J11 | rows top to bottom, outer pin (odd, nearest the board edge) / inner pin (even): 1 `GND` / 2 `SENSE`, 3 `GND` / 4 `GPIO8`, 5 `GND` / 6 `GPIO9`, 7 `GND` / 8 `GPIO20`, 9 `GND` / 10 `GPIO21`, 11 `GND` / 12 `GPIO0` | the sense wire (above), then every GPIO the board leaves unused with a ground beside it. GPIO8 is also the module's blue LED. GPIO8 and GPIO9 are ESP32-C3 strapping pins: leave them high or floating at reset (GPIO9 low at reset enters download mode). GPIO0 is a plain GPIO on the C3. GPIO20 is the pin for an OpenPuck's wake pulse (`power_switch.pins.wake`, README "Power switch"): the puck's `017` to pin 8, puck GND to pin 7, and the puck's BAT to J14's 5VSB (pin 5). GPIO0, GPIO20 and GPIO21 are the pins a `gpio:N` fan source can read a PWM signal on (the BC-250's own fan header's PWM and GND, two wires, to the GPIO and the GND beside it — never the header's +12 V; see the main README's Fans); 20 and 21 are also the J5 UART candidates, so GPIO0 first |
| J14 | rows top to bottom, both pins of a row one rail: 1+2 `5VSB`, 3+4 `3.3V`, 5+6 `12V` | optional power breakout, straight off the rails: 5VSB from the module's 5V pad (the puck's BAT goes here), 3.3V from the PSU header's pin 6, 12 V from its pin 4. The GND beside it is J11's outer column. Pin names are on the back |
| FAN1 J5 … FAN4 J8 | 1 `G`, 2 `12V`, 3 `T`, 4 `PWM` | standard 4-pin fan pinout, tach unconnected |

The fan headers are mounted rotated, so on the board their pins read
`PWM T 12V G` left to right (pin 1, GND, is the *right* pin of each header)
and every header's lock ramp faces down the board, away from the strip
connector.
The header names are the config's: FAN1 (top left) is GPIO5 and `header1` in
the config's `fans` block, FAN2 top right, FAN3 bottom left, FAN4 (bottom
right) is GPIO10 and `header4` (the header → GPIO map is `FAN_PINS` in
`tools/pincheck.py`). Each header's name is printed just below it.

The strip path is sized for 3 A: a 3 mm 3.3V trace from the header's front
3.3 V pin (the rear one is tied behind it) up the header's left side and
across the plug zone into the VH, and a 2.5 mm ground return from the VH
back to the header's ground pins, both on 1 oz copper (about 15 °C rise at
3 A). All grounds are one net; 5VSB, 3.3V and 12 V are three separate rails.
The fan block's 12 V is split: a 1.5 mm top-layer track feeds the left column
(FAN1, FAN3) and a 1.2 mm bottom-layer track the right column (FAN2, FAN4),
each good for two fans or a fan and an AIO pump with margin (about 2.7 A per
column at a 10 °C rise; a pump is 0.3–1 A, a fan 0.1–0.5 A).

J14's 3.3V and 12 V are 0.75 mm tracks, the most that fits between J11's
outer pads and the board edge with 0.5 mm to the pads: about 1.5 A each. Its
5VSB is 1.0 mm, about 2 A. None of them is the PSU's full output. 3.3V goes
west off the PSU header's pin 6 along the bottom edge and up the left edge
on the front; 12 V goes up out of the header's pin 4 into the plug zone,
west above the front row, drops to the back through a via beside the 3 A
return, comes down past the header's left end and runs the same bottom and
left edges on the back, where it passes nothing but J11's GND pins; the
button LED (10–30 mA) taps it on the way. 5VSB comes off the module's 5V
pad over the module's USB end. Both edge rails pass the bottom-left screw
(H3) between the hole and the board edge, under its head on the solder
mask, as rev C's 3.3V did: a plastic screw or a nylon washer there if the
standoff is metal.

**Ground fill.** Both copper layers are filled with GND wherever nothing
else runs, 0.5 mm from every other net and from the board edge, with
thermal spokes on every ground pad so the pads still take solder, and no
sliver narrower than 0.5 mm. Ground vias stitch the two layers every 5 mm
or so. The fill gives every signal a return path right under it (the fan
PWM and strip data lines, the GPIOs), lowers the ground's resistance for the
fans and the strip, and ties every ground pin in more than one way. It
stays out of the antenna zone under the module's end, and islands that
reach no ground are removed.

## Ordering

Three ways, from most to least finished. `make` writes an order folder per
fab under `out/fab/`: `bc250_carrier-gerbers.zip` (gerbers and drill files,
what the fab's PCB upload takes), `bom.csv` (the parts to fit, in that fab's
own column layout) and `cpl.csv` (where they go). Everything on the board is
through-hole. The parts are the LCSC numbers in the table below; `fab.py`
holds the per-fab layouts (a `PROVIDERS` table, one entry per fab). Whichever
route, the strip and button **plugs** (JST housings and crimp contacts, the
last four lines of the table) are not board parts: order them from LCSC
separately, or from anyone carrying JST VH and XH.

The Super Mini is not soldered. It plugs into two 1 × 8 low-profile sockets
(J12, J13), which are ordinary stocked parts, so an assembled board from
either fab is complete: buy any ESP32-C3 Super Mini **with the pins
soldered** (AliExpress lists them that way; pins point down, away from the
components) and push it in, USB-C at the board edge as the silkscreen
between the sockets says. It comes out again for reflashing or replacement.

### Assembled by PCBWay

1. pcbway.com → PCB Instant Quote → upload `out/fab/pcbway/bc250_carrier-gerbers.zip`
   (it also carries `assembly-top.pdf` / `assembly-bottom.pdf` as the assembly
   drawing). 2 layers, 1.6 mm, 1 oz, any colour. Add **Assembly service**:
   turnkey (PCBWay sources the parts), through-hole, top side, from 1 board.
2. Upload `out/fab/pcbway/bom.csv` and `cpl.csv` (PCBWay's own template
   columns). Every line has the manufacturer part number and, in the notes,
   its LCSC number and link, so sourcing is a lookup. J11 and J14 are left
   off (`NOT_ASSEMBLED`): cut them from two 2 × 8 headers and solder them
   yourself.
3. PCBWay reviews by hand and quotes after that (parts, a per-order assembly
   setup and per-joint labour). Answer their orientation questions from the
   silkscreen and `pinout.png`: the fan headers' lock ramp, the VH/XH housing
   walls, Q1's flat face and J1's mating face are all drawn.

### Assembled by JLCPCB

1. jlcpcb.com → upload `out/fab/jlcpcb/bc250_carrier-gerbers.zip`. PCB
   defaults; turn on **PCB Assembly**, *Standard* (through-hole parts need
   it, *Economic* is SMD-only), top side, minimum 2 assembled boards.
2. Upload `out/fab/jlcpcb/bom.csv` and `cpl.csv`. All seven lines are
   "extended" parts (a small per-part loading fee each) and were in JLCPCB's
   library with stock on 18 Sep 2026. J11 and J14 are left off
   (`NOT_ASSEMBLED`): cut them from two 2 × 8 headers and solder them yourself.
3. Check the placement preview. JLCPCB's part-orientation data does not
   always agree with KiCad's rotation for through-hole connectors; the fan
   headers' lock ramp, the VH/XH housing walls, Q1's flat face and J1's
   mating face must match the silkscreen. Rotate a part in the preview if not.
4. Note the order number and buy the plugs at lcsc.com (below) shipped
   together with it.

### Bare board, everything soldered by you

Two orders, one shipment: JLCPCB makes the board, LCSC (its sister shop)
supplies every part (the Super Mini itself comes from wherever you like),
and LCSC's checkout offers to combine the parcel with a JLCPCB order.

1. **Board.** Upload `out/fab/jlcpcb/bc250_carrier-gerbers.zip` at
   jlcpcb.com. Defaults are fine: 2 layers, 1.6 mm, 1 oz, any colour, no
   assembly. Note the JLCPCB order number.
2. **Parts.** `out/lcsc_parts.csv` is the shopping list, one line per LCSC
   stock number with the quantity already rounded up to LCSC's minimum
   order. It is sized for ten boards; `BOARDS=3 make` resizes it. Upload it to the BOM
   tool at lcsc.com (map the "LCSC Part Number" and "Quantity" columns) or
   add the numbers to the cart by hand. At checkout pick the option to ship
   together with the JLCPCB order and give its number. Same account and
   currency on both sites, and it cannot be undone once combined.

| LCSC # | part | for | per board | min. order |
|---|---|---|---|---|
| C9114 | JSCJ 2N7000, TO-92 | Q1 | 1 | 10 |
| C120103 | CCO CF1/4W-100KΩ±5%, ¼ W carbon film, axial | R1 | 1 | 100 |
| C22365658 | DLL-5569-10AW, Mini-Fit Jr 2×5 4.2 mm **right-angle** header (Molex 5569-10A2 clone, no pegs) | J1 | 1 | 5 |
| C160316 | JST B3P-VH(LF)(SN), 3.96 mm 3-pin, 10 A | J3 | 1 | 5 |
| C594232 | JST B4B-XH-A-G, 2.5 mm 4-pin (gold flash) | J9 | 1 | 5 |
| C68234 | BOOMELE 2.54-2*8P, 2×8 pin header: cut one to 2×6 (J11), one to 2×3 (J14, optional) | J11, J14 | 2 | 5 |
| C240840 | Molex 47053-1000, KK 254 4-circuit fan header, ramp over circuits 1–3 | J5–J8 | 4 | 5 |
| C55218878 | ShouHan PM2.54-1x8PZZ-H5.7, 1×8 female header, 5.7 mm low profile (Super Mini socket) | J12, J13 | 2 | 5 |
| C157899 | JST VHR-3N housing | strip plug | 1 | 10 |
| C160349 | JST SVH-21T-P1.1 crimp contact, 18–22 AWG | strip plug (3 + spares) | 5 | 100 |
| C144403 | JST XHP-4 housing | button plug | 1 | 20 |
| C140573 | JST SXH-001T-P0.6 crimp contact, 22–28 AWG | button plug (4 + spares) | 6 | 100 |

Every number, name, stock and minimum order above was checked against
LCSC's product data on 8 Sep 2026 (18 Sep 2026: the two pin headers
re-picked as one-piece parts, the fan headers swapped for the Molex part, the
module sockets added, and every line confirmed in JLCPCB's assembly
library), and the J1 datasheet was read against the footprint. Two fan
header substitutes **not** to make: BOOMELE 2.54-4AS (C41927) is, despite
its listing, a fully shrouded 2.54 mm wafer (CJT A2541 style) that a PC fan
plug cannot enter; Ckmtw W-2510S04P (C140769, the rev C first-order part)
mates, but its friction ramp runs the full four positions and a PC fan
plug's latch wall lands on it, so it had to be cut down.

The whole list is a few dollars; the minimum orders are what set the
quantities (the two crimp contacts come in bags of 100). The PSU header mates with the PSU's own plug and the fan headers
with the fans' plugs, so those need nothing. The JST contacts are crimp
type: a cheap ratchet crimper for open-barrel terminals (an SN-01BM or
similar) does both series, or solder the wire into the contact's barrel and
squeeze the insulation tabs with pliers. Use 20 AWG for the strip wires.

Two things to check when the parts arrive, before soldering:

- **Fan headers.** The Molex 47053-1000 is the header the 4-wire PC fan
  spec names: its friction-lock ramp covers circuits 1–3 and the fan plug's
  latch hooks over it, with the plug's wall beside circuit 4. It is the same
  KK 254 family as the KF2510 header the first rev C boards carried, ramp on
  the same side, so the plugs go on the same way round, now without cutting
  the ramp down. Before powering a fan, put a meter on the header and confirm
  the fan's black wire lands on the pad marked `G` and yellow/red on `12V`.
  If the plug only fits the other way round, change the fan headers' rotation
  from 180 to 0 in `generate.py` (`PARTS`, the `J5..J8` loop) and re-order,
  or re-pin the fan plug.
- **The PSU header** orientation, as described above.

## Flashing for this board

Everything is the config's: the shipped `power_switch` block already has this
board's pins (`ps_on` 3, `button` 1, `button_gnd` null — the button's second
pin is a real GND, not GPIO21 — `sense` 2, `led` 8, `wake` null, or 20 with an
OpenPuck on J11 pin 8), and `header1..header4` in
the `fans` block are FAN1..FAN4 (GPIO 5, 6, 7, 10). Set `enabled` on what you
use, then:

```sh
sudo make flash          # everything, or
sudo make flash-pwr      # just the power switch block
sudo make flash-fan      # just the fans block
```

`PWR_LED` can stay at 8: that is the Super Mini's own blue LED, so the
button-feedback blink still works.

**USB.** The Super Mini ties its USB-C VBUS straight to the 5V pin, and this
board feeds that pin from 5VSB. Plugging in a normal cable parallels the two
supplies and back-feeds the host's dead USB port while the machine is off —
the README's [5VSB and USB warning](../../README.md#power-switch) applies
unchanged: use a cable with the red wire cut. Data, flashing and the USB
host-presence detection all still work.

## Building it

- **The Super Mini goes on top, component side up, USB-C at the board's top
  edge.** Its pin names are printed on its underside, so they read mirrored
  when you flip it over to look; the carrier prints each name next to its
  hole for the module as mounted. With the module component-side up and the
  USB-C away from you, the 5V pin is the top pin of the **right** column.
  If your module differs, swap `SM_LEFT` and `SM_RIGHT` in `generate.py` —
  the nets follow the names, but the tracks are laid out for this
  arrangement and will need re-routing.
- **Check the row spacing.** Drawn at 15.24 mm (0.6″). Print
  `out/zoom-top.pdf` at 1:1 or measure the module before ordering.
- **The USB-C legs.** Many Super Minis have the USB-C shell soldered through
  the board, leaving solder bumps underneath. If yours does, mount the module
  on ~1 mm pin stubs (or cut pin-header pins short) rather than dead flat; the
  carrier has no copper on the top layer under the module, only its own pads
  (the fan PWM lines run under its USB end on the *bottom* layer). The
  module's top edge is 3.9 mm inside the board edge, so a USB-C plug's
  overmould hangs over the carrier — it clears, there is nothing under it.
- **Antenna.** The module's ceramic antenna sits at the end away from the
  USB-C. The carrier keeps a copper-free zone under it: no tracks, and the
  ground fill stops at its edge (the fill under the rest of the module is on
  the back only), so BLE range is whatever the Super Mini manages on its own.
- **The PSU header** solders with its housing over the front pin row and its
  face pointing up the board; the two pegs snap into the 3 mm holes. Nothing
  may be placed in the plug zone in front of it.
- **J11** carries the sense wire (pin 2) and the spare GPIOs; J14 the rails.
  Cut a 2 × 8 pin header to 2 × 6 for J11 and another to 2 × 3 for J14 (or
  leave J14 off, and solder the sense wire straight into J11 pin 2 if you do
  not want a header at all). J11 sits in the strip between the board's left
  edge and the module's left pin column, so that column has no pin names
  printed (the right column's names orient the module); both headers' pin
  names are printed on the **back** of the board, readable with the board
  flipped. The button connector J9 sits 0.75 mm from a 5.6 mm pan head on
  H3, no room for a washer. (KiCad's DRC flags that as a courtyard
  overlap because the stock M3 footprint draws a 6.9 mm courtyard; `drc.py`
  reports it and does not fail on it.)
- Q1's flat face follows the silkscreen outline (pins D, G, S left to right
  as printed); R1 has no polarity. Q1 sits on the wide TO-92 footprint, so
  bend its outer legs out to the 2.54 mm holes. The stock 1.27 mm footprint
  left 0.3 mm between the gate and drain pads, and a bridge there puts
  PS_ON# straight onto GPIO3: the PSU stays on whatever the firmware does,
  and with the MOSFET removed it clicks as the pin changes state. If a
  board behaves like that, meter PS_ON# (J1 pin 8) to Q1's middle hole
  with everything unplugged; it must read open.

## Before the first power-up

A few meter checks catch every fault the hand-soldered boards have had so
far. Do them with the Super Mini out of its sockets and nothing plugged in:
no PSU, fans, strip or button. Pin numbers are the PSU header's (J1: edge row
3.3V GND PS_ON GND GND = pins 6–10, inner row 3.3V GND 5VSB 12V 12V = pins
1–5, left to right). Measure resistance, red probe on the first point; the
first row in diode mode, which is what shows a reversed Q1.

| red probe | black probe | expect | a low reading means |
|---|---|---|---|
| PS_ON (pin 8) | GND (pin 7) | open (diode mode: no reading) | a bridge to ground; a diode drop (~0.5 V) means **Q1 is fitted backwards**. Either way the PSU will stay on |
| PS_ON (pin 8) | Q1's middle hole (gate) | open | a bridge at Q1: GPIO3 drives PS_ON directly, the PSU sticks on or clicks |
| Q1's middle hole (gate) | GND (pin 7) | about 100 kΩ | 0 Ω: gate bridged to ground; open: R1 not soldered |
| 12V (pin 4) | GND (pin 2), 3.3V (pin 1), 5VSB (pin 3), PS_ON (pin 8) | open, each | a bridge under the header: the PSU trips or feeds 12 V into the rest |
| 5VSB (pin 3) | GND (pin 2) | open | a 5VSB short: the PSU's standby supply ticks, the module can burn |
| 3.3V (pin 1) | GND (pin 2) | open | a strip-rail short |

Then power up in two steps. First plug in the PSU **without** the Super Mini:
the PSU must stay silent and off, and the socket's 5V pin (top of the right
column) reads about 5 V. Unplug the PSU, fit the module, plug the PSU back
in. Look at the back of the header and Q1 under a bright light before each
step; that is where the bridges were.

The header's 3.3V and GND pins sit on wide copper that pulls heat away, so
they take longer to wet than the others: a larger tip or a few seconds more
there, and check that the solder has flowed round the whole pin.

## Editing

The whole design is `generate.py`: parts, nets, placement and every track.
Edit it and run `make`, which regenerates the KiCad files, runs `check.py`
(copper ≥ 0.5 mm from any other part's solder pad — the board is hand
soldered — and ≥ 0.3 mm track to track, edge ≥ 0.3 mm, no track copper in
the antenna zone, every net one connected piece — pads are checked as their true
rectangles, which is what lets tracks pass between the header's pads), runs
KiCad's real DRC through `drc.py` (the `pcbnew` Python module; fails on any
error except the mounting-hole courtyard overlap above), renders
`out/preview.png` plus `out/preview-F.png` / `out/preview-B.png` (one copper
layer each; a quick Pillow drawing of the layout and, when `pcbnew` is there,
the ground fill)
and exports `out/`. The KiCad files are ordinary KiCad 7 files too — open
`bc250_carrier.kicad_pro` and edit in the GUI if you prefer; then the
generator no longer describes the board, so pick one.

`make generate` runs `generate.py` and then `fill.py`, which fills the
ground zones with KiCad's own filler, drops a stitching via wherever both
layers' fill has room for one (at least 5 mm apart, 0.5 mm clear of every
other hole), and fills again. The fill and the stitches are not in
`generate.py`'s geometry, so `check.py` does not see them; KiCad's DRC does,
and fails on anything left unconnected.

The design's own vias are listed in `VIAS` and treated as two-layer pads by
the check: two on GATE (it hops a vertical on each layer) and one where the
12 V for the button LED and J14 drops to the back beside the 3 A return.
Everything else changes layer through the through-hole pads. The button's
ground reaches the module's GND pad up the module's right side, just outside
the antenna zone.

KiCad 7's `kicad-cli` cannot run DRC or ERC (those came with KiCad 8); the
DRC comes from `drc.py` instead, ERC has no stand-in. The remaining DRC
warnings are silkscreen text touching footprint outlines by hundredths of a
millimetre.

Fab settings: 2 layers, 1.6 mm, 1 oz copper, min track 0.5 mm, min
clearance 0.3 mm, min drill 0.5 mm (the vias) — any board house's cheapest
tier. Stock symbols and footprints are copied from the local KiCad install
(`KICAD_SHARE=/usr/share/kicad`), so the project opens without extra
libraries.

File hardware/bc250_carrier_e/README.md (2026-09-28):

# BC-250 carrier board (rev E)

Rev E is the same carrier as [rev D](../bc250_carrier/README.md), with the same
parts, nets and firmware, laid out differently: **every plug sits on the left,
the PSU header at the board's right-hand end, and the module directly beside
it.** The fans run down the left edge, the breakouts, the button and the strip
sit in a column beside them, and no signal has to cross the PSU plug's zone.
76.8 × 34.5 mm (rev D: 80 × 34.5), two layers.

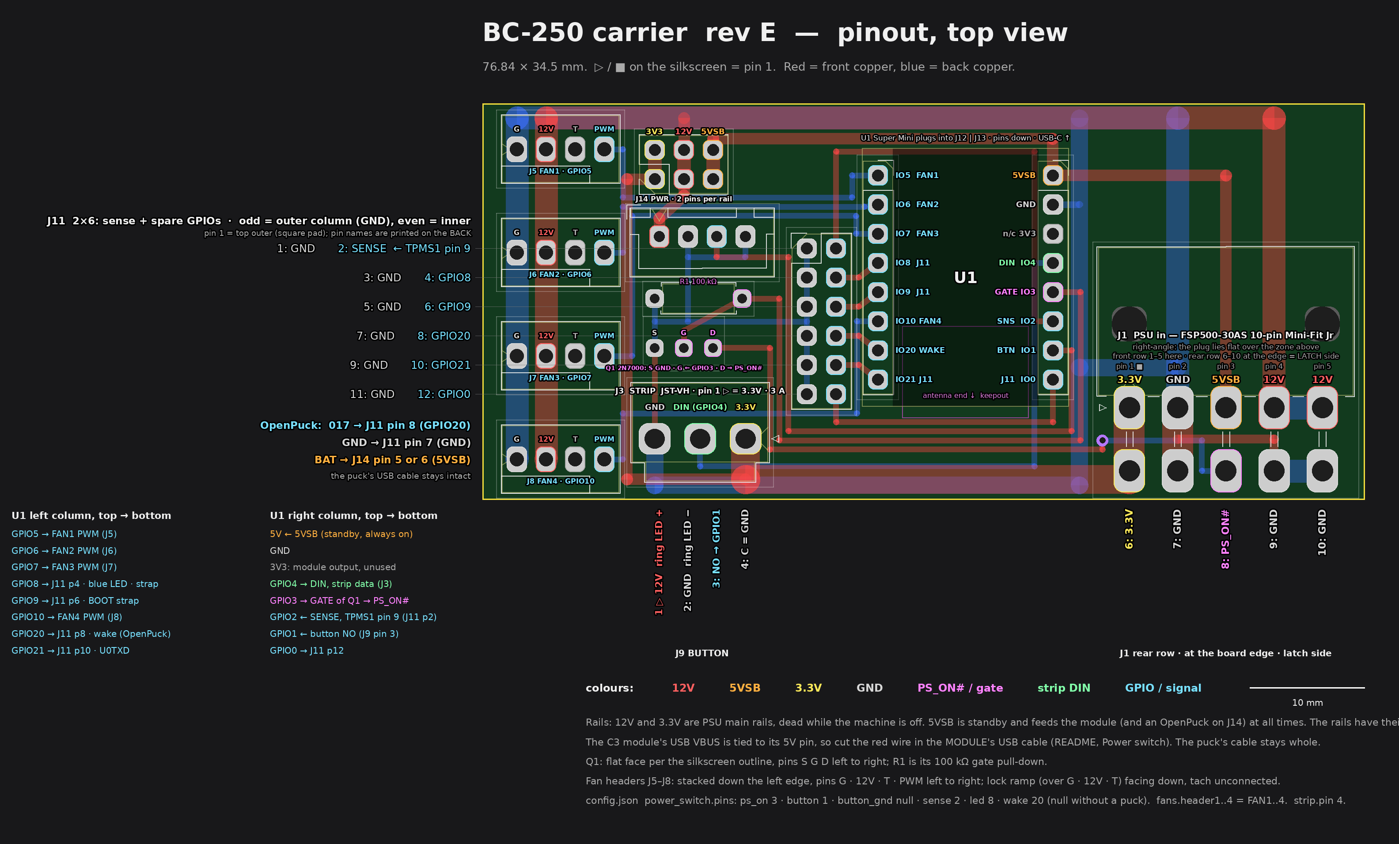
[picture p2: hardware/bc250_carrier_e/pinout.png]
Annotated pinout of rev E: every pad labelled with its rail, GPIO and role


*`make pinout` → `pinout.png`, drawn from `generate.py`'s geometry. Open it
at full size for soldering.*

Both revisions stay buildable side by side: rev D in `hardware/bc250_carrier/`,
rev E here. The tools (`check.py`, `drc.py`, `fill.py`, `preview.py`,
`fab.py`, `zoom.py`) are copies of rev D's and work the same way; only
`generate.py` and `pinout.py` differ.

## Layout

Left to right:

- **The four fan headers** stacked down the left edge, 9 mm apart, pins
  G · 12V · T · PWM left to right, lock ramps facing down. Their 12 V and GND
  are two bars down the column.
- **Column C**, top to bottom: the power breakout **J14**, the button **J9**,
  **R1**, **Q1** and the strip **VH (J3)**. The fan PWM lines cross it in
  three lanes between J14 and J9 (FAN4's between Q1 and the VH).
- **J11** (the sense wire and the spare GPIOs), right beside the module's
  left pad column.
- **The Super Mini** in its two sockets (J12, J13), USB-C at the top edge.
  Nothing sits under it, so it can still be soldered flat instead of
  socketed.
- **The PSU header (J1)** directly beside the module at the right-hand end,
  the same right-angle Mini-Fit Jr as rev D, facing the same way: the plug
  lies flat over the board's right quarter and its wires leave over the top
  edge. Everything above the header is the **plug zone**: tracks only,
  nothing taller than the solder mask.

The module's right pads (DIN, GATE, BTN, GPIO0) face the PSU header, so their
lines go round the module: down the gap between it and the header (6.7 mm between their pin columns) (or
inside its right pad column) and west along the bottom edge under its antenna
end, next to the strip's 3 A feed from the header's 3.3V pin.

No mounting holes: the plug zone has to stay flat and every other spot is
taken. The repo's case isn't used with this board.

## What is on it

The same parts as rev D (see its ordering table; J11 and J14 are still cut
from 2 × 8 pin headers and left off assembly orders).

The rev C fan headers (Ckmtw W-2510S04P, KF2510) fit the same holes, but
only just: their body is 12.7 mm long (the Molex's about 10.2), so FAN2's
reaches about 0.2 mm into J9's housing and FAN3's and FAN4's about 0.15 mm
into J3's. Dry-fit first: fit J9 and J3, then push each fan header towards
the left edge while soldering it (the pins have about 0.15 mm of play in
their holes); if one still won't sit flat, file about 0.3 mm off the end
facing column C. Their lock ramp spans all four pins, so it needs cutting
down as on rev C; fit them with the ramp facing down the board, as the
silkscreen shows. A fan plug as long as 12.7 mm would just touch J9 or J3
when plugged in (not checked on a real plug).

| ref | part | where |
|---|---|---|
| J5–J8 | four Molex 47053-1000 fan headers, stacked, pins G 12V T PWM left to right | left edge |
| J14 | 2 × 3 power breakout, turned: three columns 3V3, 12V, 5VSB, two pins each | column C, top |
| J9 | JST-XH 4-pin button connector: pins 12V, GND, NO, C left to right | column C |
| R1, Q1 | 100 kΩ; 2N7000 on the wide TO-92 footprint (S G D left to right) | column C |
| J3 | JST-VH strip connector, turned 180: GND, DIN, 3.3V left to right | column C, bottom |
| J11 | 2 × 6: SENSE + five spare GPIOs, GND beside each (as rev D) | between column C and the module |
| U1 on J12 + J13 | ESP32-C3 Super Mini in two 1 × 8 low-profile sockets | beside the PSU header |
| J1 | PSU header, Mini-Fit Jr 5569-10A2 right-angle | right-hand end |

## Wiring

| connector | pins | goes to |
|---|---|---|
| PSU J1 | as rev D ([the PSU header](../bc250_carrier/README.md#the-psu-header)) | the FSP500-30AS 10-pin plug, straight on |
| STRIP J3 | 1 `3.3V`, 2 `DIN`, 3 `GND`; pin 1 is the **right** pin | the WS2812B strip; DIN is GPIO4 |
| BUTTON J9 | 1 `12V`, 2 `GND`, 3 `NO`, 4 `C`; pin 1 is the **left** pin | the illuminated button as on rev D: 1–2 the ring LED (12 V), 3 the normally-open contact → GPIO1, 4 the switch's common (a real GND) |
| J11 | 1 `GND` / 2 `SENSE`, 3 / 4 `GPIO8`, 5 / 6 `GPIO9`, 7 / 8 `GPIO20`, 9 / 10 `GPIO21`, 11 / 12 `GPIO0` (odd pins GND) | as rev D: the sense wire (BC-250 TPMS1 pin 9) on pin 2; OpenPuck `017` → pin 8, its GND → pin 7 |
| J14 | columns left to right: pins 1+2 `3.3V`, 3+4 `12V`, 5+6 `5VSB` | optional rail breakout; an OpenPuck's BAT goes on 5VSB (pin 5 or 6) |
| FAN1 J5 … FAN4 J8 | left to right: `G`, `12V`, `T`, `PWM` | standard 4-pin fans, tach unconnected; FAN1..4 = GPIO 5, 6, 7, 10 = `header1..4` in the config, top to bottom. The lock ramps face down the board |

The config is unchanged from rev D: the same `power_switch` pins, the same
fan headers, `strip.pin` 4.

## Routing

The rule from rev D holds: on the back, where every joint is soldered, **12 V
passes no pad of 5VSB, GATE, 3.3V, PS_ON# or any GPIO within 1 mm.** The
only 12 V on the back is the PSU header's own pin 4-5 tie (J14's pins sit
0.84 mm apart at the 2.54 mm pitch, as on any header). A slipped bridge on the
back can short a rail to ground or switch the PSU, never feed 12 V into the
module. On the front, under FAN1's plastic, the top-edge 12 V passes FAN1's
PWM pin at 0.6 mm.

- **12 V** leaves the PSU header's pin 4 straight up through the plug zone
  and runs along the top edge on the front (2 mm, ~3.5 A), then down the
  fans' 12V pins as a bar. J14's 12 V column taps it, and J9's LED is fed
  from that column on the front.
- **The fans' ground** runs along the top edge on the back, right under the
  12 V, and down the fans' G pins, so the fan current's loop is one narrow
  strip. At the other end it drops into the PSU header's pin 2. A **ground
  spine** runs down the back of the gap between the module and the header,
  from the top edge to the bottom edge; the module's GND pad joins it, a
  branch goes over pin 1 into pin 2, and the strip's 3 A return comes east
  along the bottom edge from the VH's GND pin into it. J9's, J11's, Q1's and
  R1's grounds have a web of their own down column C into the VH's GND pin,
  and the ground fill on both layers, stitched with ground vias, ties in
  everything else.
- **3.3V** (3 A) leaves the header's pin 6 as a 2.5 mm track west along the
  bottom edge on the front, into the VH's pin 1. On from there, narrower, it
  runs under the VH's other pins to the gap by the fans and up it into J14's
  3V3 column.
- **5VSB** runs from the header's pin 3 up through the plug zone into the
  module's 5V pin (front), and on over the module's top to J14's 5VSB column.
- **The fan PWM lines** run west on the back: FAN1's to FAN3's off the
  module's top three pads, in three lanes under J14 to the gap by the fans,
  then up or down into each pin 4. FAN4's goes down between J11 and the
  module, under J11 and over the VH's pins.
- **DIN** goes down the back inside the module's right pad column (0.5 mm
  from the pads, clear of the antenna zone), west along the bottom and up
  into the VH's pin 2. **SENSE** goes up the same lane on the front and over
  the module's top into J11. **GPIO0** drops off its pad and goes west under
  the module's end into J11's bottom row.
- **BTN** and **GATE** go east off their pads, down the gap by the header,
  west along the bottom edge and up between column C and J11: BTN under J9
  into its pin 3, GATE into R1's pin 1 and on to Q1's gate. **PS_ON#** leaves
  the PSU header's pin 8 through the gap between its pin rows on the back,
  changes to the front through a via just past the header's left end and
  follows them into Q1's drain.

Clearances as rev D: 0.5 mm from any solder pad to copper of another net,
0.3 mm track to track, 0.5 mm fill clearance; `check.py` and KiCad's DRC are
both clean.

## Building, checking, ordering

As rev D: [building it](../bc250_carrier/README.md#building-it),
[before the first power-up](../bc250_carrier/README.md#before-the-first-power-up)
(the PSU header's pins are numbered the same; on rev E Q1's middle hole is
still the gate), [ordering](../bc250_carrier/README.md#ordering) (`make`
writes `out/fab/` here too) and [flashing](../bc250_carrier/README.md#flashing-for-this-board).
Q1's legs are printed S G D on rev E (left to right), the opposite way round
from rev D's D G S: follow the silkscreen outline.

`make` regenerates the KiCad files (`bc250_carrier_e.*`), fills and stitches
the ground, runs `check.py` and KiCad's DRC, renders `out/preview.png` (plus
`preview-F.png` / `preview-B.png`, one layer each) and `pinout.png`, and
exports gerbers, PDFs and the fab folders into `out/`.

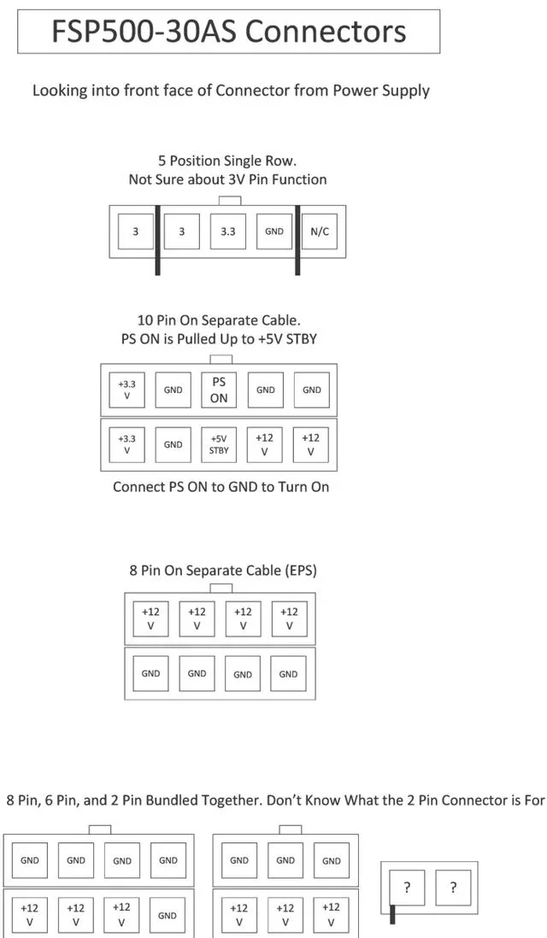
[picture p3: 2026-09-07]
hardware/bc250_carrier/fsp500-30as.webp

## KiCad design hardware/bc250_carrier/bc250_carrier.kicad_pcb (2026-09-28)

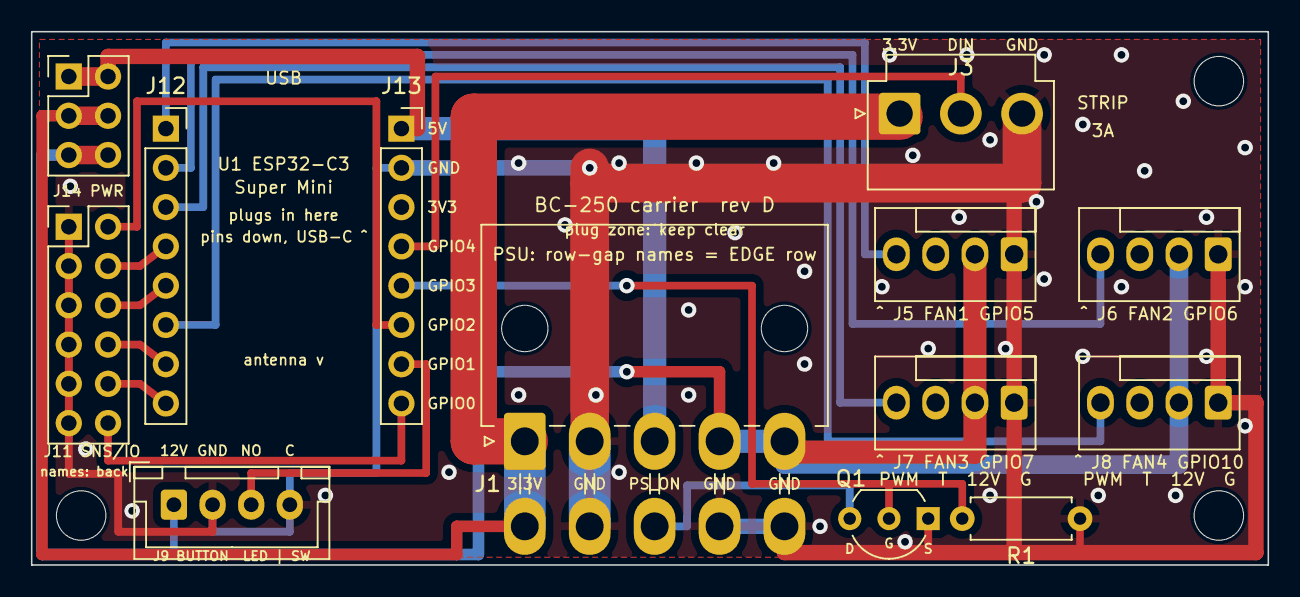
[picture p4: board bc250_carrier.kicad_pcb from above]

Board: 2 copper layers, 80.0 x 34.5 mm, 16 parts (0 on the bottom side), 18 nets.

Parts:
H2, H3, H4: M3; MountingHole_3.2mm_M3
J1: PSU Mini-Fit Jr 2x5 R/A; Molex_Mini-Fit_Jr_5569-10A2_2x05_P4.20mm_Horizontal
J3: STRIP; JST_VH_B3P-VH_1x03_P3.96mm_Vertical
J5: FAN1 GPIO5; Molex_KK-254_AE-6410-04A_1x04_P2.54mm_Vertical
J6: FAN2 GPIO6; Molex_KK-254_AE-6410-04A_1x04_P2.54mm_Vertical
J7: FAN3 GPIO7; Molex_KK-254_AE-6410-04A_1x04_P2.54mm_Vertical
J8: FAN4 GPIO10; Molex_KK-254_AE-6410-04A_1x04_P2.54mm_Vertical
J9: BUTTON; JST_XH_B4B-XH-A_1x04_P2.50mm_Vertical
J11: SENSE+GPIO/GND; PinHeader_2x06_P2.54mm_Vertical
J12: U1 socket L; PinSocket_1x08_P2.54mm_Vertical
J13: U1 socket R; PinSocket_1x08_P2.54mm_Vertical
J14: PWR 3.3V/5VSB/12V (optional); PinHeader_2x03_P2.54mm_Vertical
Q1: 2N7000; TO-92_Inline_Wide
R1: 100k; R_Axial_DIN0207_L6.3mm_D2.5mm_P7.62mm_Horizontal

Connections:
3.3V: J1.1, J1.6, J3.1, J14.3, J14.4
5VSB: J1.3, J13.1, J14.1, J14.2
12V: J1.4, J1.5, J5.2, J6.2, J7.2, J8.2, J9.1, J14.5, J14.6
BTN: J9.3, J13.7
DIN: J3.2, J13.4
FAN_GPIO5: J5.4, J12.1
FAN_GPIO6: J6.4, J12.2
FAN_GPIO7: J7.4, J12.3
FAN_GPIO10: J8.4, J12.6
GATE: J13.5, Q1.2, R1.1
GND: J1.2, J1.7, J1.9, J1.10, J3.3, J5.1, J6.1, J7.1, J8.1, J9.2, J9.4, J11.1, J11.3, J11.5, J11.7, J11.9, J11.11, J13.2, Q1.1, R1.2
GPIO0: J11.12, J13.8
GPIO8: J11.4, J12.4
GPIO9: J11.6, J12.5
GPIO20: J11.8, J12.7
GPIO21: J11.10, J12.8
PS_ON#: J1.8, Q1.3
SENSE: J11.2, J13.6

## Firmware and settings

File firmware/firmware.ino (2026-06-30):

#include <Freenove_WS2812_Lib_for_ESP32.h>
#include <Preferences.h>
#include <LittleFS.h>

// shared with the host (copied into src/ by `make receiver`): the wire
// protocol, the streaming frame parser, and the recording format + replay
// logic. The receiver renders no effects — the daemon records the power-on/
// shutdown animations to frames and streams them here (CMD_REC_*); this
// firmware stores them in flash and replays them. So an effect tweak no longer
// means a reflash; it's picked up on the next daemon start and shown one power
// cycle later. The only device-specific parts left are LittleFS save/load, the
// WS2812 output, the UART, and millis() — everything else is common/recording.hpp.
#include "src/protocol.hpp"
#include "src/receiver.hpp"
#include "src/recording.hpp"
#include "src/fade.hpp"

#define CHANNEL 0
#define MAX_LEDS 2048

// TEMP diagnostic: uncomment to bypass the whole host/recording path and drive
// the strip directly from setup(). Proves the C3 + Freenove lib + our
// initStrip()/show() actually light the strip on this pin, independent of the
// daemon link. Set the pin/count to your wiring. Remove (or recomment) and
// reflash once confirmed. See the LED_SELFTEST block in setup().
// #define LED_SELFTEST
#define LED_SELFTEST_PIN 4
#define LED_SELFTEST_COUNT 30

// boot-time baud; `make flash` overrides this with serial.baud from the host
// config. The receiver re-hunts (below) when traffic doesn't decode and
// remembers the rate that worked, so this only sets how fast the first lock
// happens
#ifndef HOST_BAUD
#define HOST_BAUD 921600
#endif

// blank the strip when the host stops sending (crash, unplug); the last frame
// would otherwise stay lit forever. `make flash` overrides this with
// serial.host_timeout_ms from the host config
#ifndef HOST_TIMEOUT_MS
#define HOST_TIMEOUT_MS 5000
#endif

// when bytes keep arriving but never form a valid frame, the host is probably
// talking at another rate: step through the candidates (the same set the
// host's baudToSpeed() supports) until frames decode. Even the slowest replay
// shows a frame well inside 500 ms, so that's enough per candidate to
// recognize a lock. A silent line never hunts, so a host that merely stopped
// finds the receiver where it left it
#define HUNT_AFTER_MS 500
#define HUNT_MIN_BYTES 64

// the recording files live here; one per slot (see common/protocol.hpp)
#define REC_PATH_POWER_ON "/boot.rec"
#define REC_PATH_SHUTDOWN "/shutdown.rec"

// upper bound on one recording (frameCount*count*3) so a corrupt header can't
// trigger a huge allocation; far above any real animation (~tens of KB)
#define REC_MAX_BYTES (512u * 1024u)

const uint32_t BAUDS[] = {
    9600, 19200, 38400, 57600, 115200, 230400, 460800, 500000,
    921600, 1000000, 1500000, 2000000};
const size_t NUM_BAUDS = sizeof BAUDS / sizeof BAUDS[0];

Freenove_ESP32_WS2812 *strip = nullptr;

uint16_t currentCount = 0;
uint8_t currentPin = 13;

// the OS takes a while to start the daemon, so between power-on and the first
// host frame the receiver replays its stored power-on recording (instead of
// sitting dark). The same player runs the shutdown recording after the host
// sends a shutdown command and exits.
bool hostSeen = false;
bool shuttingDown = false; // replaying the shutdown recording (host has gone)

// the recording currently playing (held in RAM so re-recording its on-flash
// file can never race playback), and the shared stepper that paces it
rec::Recording active;
rec::Player player;

// incoming recording being streamed from the host, accumulated in RAM by the
// shared receiver and committed to flash on END (one write — so flash stalls
// can't drop UART bytes mid-stream). recSlot is the slot its END must name.
rec::RecordingReceiver recRx;
uint8_t recSlot = 0;

unsigned long lastFrameMs = 0;
unsigned long lastHuntMs = 0;
size_t baudIdx = 0;
bool blanked = false;

// crossfading, owned here (and mirrored by the host's viewer) rather than by
// the daemon: we keep the last frame shown and, when the incoming animation's
// id changes, dissolve the new one in over it with the shared fader. Every
// frame — live (onPixels) or replayed (boot/shutdown recordings) — goes through
// show() below carrying an id, so the boot→live and live→shutdown handoffs are
// just ordinary id changes; there's no "am I replaying?" state to track. Live
// ids ride the wire; replay frames get a reserved per-slot id (proto::ANIM_*),
// which the firmware knows from the slot it's playing (see common/fade.hpp).
fade::Fader fader;
uint8_t lastShown[MAX_LEDS * 3]; // last frame written to the strip
uint8_t frameBuf[MAX_LEDS * 3];  // scratch: the incoming frame, blended in place
uint16_t lastAnimId = proto::ANIM_NONE; // id of the frame on screen
uint16_t lastShownCount = 0;     // its LED count: a dissolve needs matching geometry
uint16_t replayXms = 0;          // crossfade ms for a shutdown replay (from CMD_SHUTDOWN)

// the last rate that produced valid frames, persisted in NVS so a host baud
// change without a reflash costs one hunt per change, not one per power cycle
Preferences prefs;
uint32_t currentBaud = HOST_BAUD;
uint32_t savedBaud = 0;
uint32_t savedFlashed = 0;

// strip geometry from the last valid host frame, persisted so a never-recorded
// board can still bring the strip up (blank) on the right pin/count before the
// host arrives; a loaded recording's own geometry outranks it
uint16_t savedCount = 0;
uint8_t savedPin = 0;

const char* recPath(uint8_t slot)
{
    return slot == proto::SLOT_SHUTDOWN ? REC_PATH_SHUTDOWN : REC_PATH_POWER_ON;
}

void initStrip(uint16_t count, uint8_t pin)
{
    if (strip)
    {
        delete strip;
        strip = nullptr;
    }

    strip = new Freenove_ESP32_WS2812(count, pin, CHANNEL, TYPE_GRB);
    strip->begin();

    currentCount = count;
    currentPin = pin;
}

void blankStrip()
{
    if (!strip)
        return;

    for (uint16_t i = 0; i < currentCount; i++)
        strip->setLedColorData(i, 0, 0, 0);

    strip->show();

    // the strip is black now: record that as the last shown, under a sentinel
    // id, so the next frame (a returning host, or a replay) dissolves up from
    // black rather than snapping
    if ((size_t)currentCount * 3 <= sizeof lastShown)
    {
        memset(lastShown, 0, (size_t)currentCount * 3);
        lastShownCount = currentCount;
    }
    lastAnimId = proto::ANIM_NONE;
}

// the one place a frame reaches the strip. Every source — live frames and
// replayed recordings alike — calls this with the animation's id; when the id
// differs from what's on screen we dissolve the new frame in over the last
// (as long as the geometry matches), then remember it. That single rule covers
// live switches, the boot→live handoff and the live→shutdown handoff, so no
// source needs to special-case transitions (see common/fade.hpp).
void show(uint16_t animId, uint16_t count, uint16_t xms, const uint8_t* px)
{
    if (!strip || (size_t)count * 3 > sizeof frameBuf)
        return;

    uint32_t now = millis();

    // a new animation, and the held frame still lines up: start the dissolve
    if (animId != lastAnimId && count == lastShownCount)
        fader.begin(lastShown, count, xms, now);

    lastAnimId = animId;

    memcpy(frameBuf, px, (size_t)count * 3);
    fader.apply(frameBuf, count, now);

    for (uint16_t i = 0; i < count; i++)
        strip->setLedColorData(i, frameBuf[i * 3], frameBuf[i * 3 + 1],
                               frameBuf[i * 3 + 2]);
    strip->show();

    memcpy(lastShown, frameBuf, (size_t)count * 3);
    lastShownCount = count;
}

// device side of the recording store: LittleFS read/write around the shared
// header codec (common/recording.hpp). The format and field layout live there.
bool loadRecording(uint8_t slot, rec::Recording& out)
{
    File f = LittleFS.open(recPath(slot), "r");
    if (!f)
        return false;

    uint8_t hdr[rec::Recording::kHeaderLen];
    if (f.read(hdr, sizeof hdr) != sizeof hdr || !out.decodeHeader(hdr))
    {
        f.close();
        return false;
    }

    size_t bytes = (size_t)out.frameCount * out.frameBytes();
    if (out.count == 0 || out.count > MAX_LEDS || out.frameCount == 0 ||
        bytes > REC_MAX_BYTES)
    {
        f.close();
        return false;
    }

    out.data.resize(bytes);
    bool ok = f.read(out.data.data(), bytes) == bytes;
    f.close();

    if (!ok)
    {
        out.clear();
        return false;
    }

    return true;
}

void saveRecording(uint8_t slot, const rec::Recording& r)
{
    File f = LittleFS.open(recPath(slot), "w");
    if (!f)
        return;

    uint8_t hdr[rec::Recording::kHeaderLen];
    r.encodeHeader(hdr);
    f.write(hdr, sizeof hdr);

    if (!r.data.empty())
        f.write(r.data.data(), r.data.size());

    f.close();
}

// the hash stored in a slot's file, or 0 if missing/invalid; lets begin()
// decide whether an upload is unchanged without reading the whole file
uint32_t storedHash(uint8_t slot)
{
    File f = LittleFS.open(recPath(slot), "r");
    if (!f)
        return 0;

    uint8_t hdr[rec::Recording::kHeaderLen];
    bool ok = f.read(hdr, sizeof hdr) == sizeof hdr;
    f.close();

    return ok ? rec::Recording::headerHash(hdr) : 0;
}

// start replaying whatever is in `active`, re-initing the strip if the
// recording's geometry differs from what's currently up
void beginReplay()
{
    if (active.valid() &&
        (active.count != currentCount || active.pin != currentPin))
        initStrip(active.count, active.pin);

    player.start(&active);
}

// a validated command frame from the host
void handleCommand(uint8_t cmd, const uint8_t* payload, uint16_t len)
{
    if (cmd == proto::CMD_SHUTDOWN)
    {
        // the host has sent this and exited; replay the stored shutdown
        // recording to completion, then stay dark. hostSeen stops the
        // power-on path from resuming.
        hostSeen = true;
        shuttingDown = true;

        // optional 2-byte payload: how long to dissolve from the last live
        // frame into the shutdown recording (see protocol.hpp). The replay path
        // stamps proto::ANIM_SHUTDOWN on those frames, so the dissolve happens
        // through show() like any other id change — no special-casing here.
        replayXms = len >= 2 ? (uint16_t)(payload[0] | (payload[1] << 8)) : 0;

        if (loadRecording(proto::SLOT_SHUTDOWN, active))
            beginReplay();
        else
            blankStrip(); // nothing recorded yet
    }
    else if (cmd == proto::CMD_REC_BEGIN)
    {
        rec::BeginInfo bi;
        if (bi.decode(payload, len))
        {
            recSlot = bi.slot;
            // unchanged upload (hash matches the stored file): drop it instead
            // of rewriting flash
            recRx.begin(bi, bi.hash == storedHash(bi.slot));
        }
    }
    else if (cmd == proto::CMD_REC_FRAME)
    {
        recRx.frame(payload, len);
    }
    else if (cmd == proto::CMD_REC_END)
    {
        // commit the buffered recording in one write (no mid-stream stalls); a
        // skipped/short/mismatched upload just clears state
        if (recRx.complete() && len >= 1 && payload[0] == recSlot)
            saveRecording(recSlot, recRx.rec);

        recRx.reset();
    }
}

// the host endpoint: a proto::FrameHandler that drives the real strip. The
// shared parser (src/receiver.hpp) does all the AA-55 framing and checksum
// work and calls these when a clean frame lands, so this side only says what a
// frame *means* on the hardware. The same handler interface the on-screen
// viewer implements (host/virtual_strip.cpp).
struct StripHandler : proto::FrameHandler
{
    void onPixels(uint8_t pin, uint16_t count, uint16_t anim, uint16_t xms,
                  const uint8_t* rgb) override
    {
        if (pin != currentPin || count != currentCount)
        {
            // pixels past the new count (or on the old pin) would otherwise
            // latch their last color forever
            if (strip && (count < currentCount || pin != currentPin))
                blankStrip();

            initStrip(count, pin);
        }

        // a switch (the anim id changed) dissolves; a geometry change snaps,
        // since show() only fades when the held frame's count still matches
        show(anim, count, xms, rgb);

        lastFrameMs = millis();
        blanked = false;
        hostSeen = true;

        // the host is (back) in control: drop any standalone replay and free
        // its RAM, and clear the shutdown latch so a stop/start resumes cleanly
        shuttingDown = false;
        player.stop();
        if (active.frameCount)
            active.clear();

        // a checksummed frame proves this rate works; writes happen only when
        // something actually changed, so NVS wear is one write per baud change
        // or reflash
        if (currentBaud != savedBaud || savedFlashed != HOST_BAUD)
        {
            prefs.putUInt("baud", currentBaud);
            prefs.putUInt("flashed", HOST_BAUD);
            savedBaud = currentBaud;
            savedFlashed = HOST_BAUD;
        }

        // remember the geometry so a never-recorded board can still bring the
        // strip up before the host arrives next time
        if (currentCount != savedCount || currentPin != savedPin)
        {
            prefs.putUShort("count", currentCount);
            prefs.putUChar("pin", currentPin);
            savedCount = currentCount;
            savedPin = currentPin;
        }
    }

    void onCommand(uint8_t cmd, const uint8_t* payload, uint16_t len) override
    {
        handleCommand(cmd, payload, len);
    }
};

StripHandler handler;
proto::Receiver receiver(handler, MAX_LEDS);

void setup()
{
#ifdef LED_SELFTEST
    // hardware proof: cycle the strip red -> green -> blue forever on the
    // wired pin, with nothing else running. If this lights up, the C3 runs our
    // strip code fine and the dark strip is a daemon-link/config problem, not
    // the chip. If even this stays dark, it's wiring/pin/lib, not the host.
    initStrip(LED_SELFTEST_COUNT, LED_SELFTEST_PIN);
    const uint8_t colors[3][3] = {{40, 0, 0}, {0, 40, 0}, {0, 0, 40}};
    for (uint8_t c = 0;; c = (c + 1) % 3)
    {
        for (uint16_t i = 0; i < LED_SELFTEST_COUNT; i++)
            strip->setLedColorData(i, colors[c][0], colors[c][1], colors[c][2]);
        strip->show();
        delay(700);
    }
#endif

    prefs.begin("ledrx", false);
    savedBaud = prefs.getUInt("baud", 0);
    savedFlashed = prefs.getUInt("flashed", 0);
    savedCount = prefs.getUShort("count", 0);
    savedPin = prefs.getUChar("pin", 13);

    // trust the remembered rate only if the firmware default is the same one
    // it was saved under — a reflash with a new HOST_BAUD means the host
    // config changed, so the new default outranks it
    if (savedBaud != 0 && savedFlashed == HOST_BAUD)
        currentBaud = savedBaud;

    // a bigger RX buffer so a recording upload (many frames back-to-back)
    // can't outrun us while we copy each frame into RAM
    Serial.setRxBufferSize(1024);
    Serial.begin(currentBaud);

    // align the hunt cycle with the boot baud when it's in the list
    for (size_t i = 0; i < NUM_BAUDS; i++)
        if (BAUDS[i] == currentBaud)
            baudIdx = i;

    recRx.maxBytes = REC_MAX_BYTES;

    LittleFS.begin(true); // format on first boot if there's no filesystem yet

    // start replaying the stored power-on recording immediately; the first host
    // frame drops it and takes over (see onPixels). With no recording yet,
    // bring the strip up blank on the last known geometry so a never-recorded
    // board isn't undefined.
    if (loadRecording(proto::SLOT_POWER_ON, active))
        beginReplay();
    else if (savedCount > 0 && savedCount <= MAX_LEDS)
        initStrip(savedCount, savedPin);
}

void loop()
{
    // drain whatever the UART has and push it through the shared parser
    // (src/receiver.hpp); it carries state across these chunks, recognizes
    // complete frames and calls the StripHandler, which lights the strip
    // (onPixels) or acts on a command (onCommand).
    while (Serial.available())
    {
        uint8_t chunk[256];
        int avail = Serial.available();
        int want = avail < (int)sizeof chunk ? avail : (int)sizeof chunk;
        int n = Serial.readBytes(chunk, want);

        if (n > 0)
            receiver.feed(chunk, (size_t)n);
    }

    unsigned long now = millis();

    // only after the host has talked once, and only when no shutdown replay
    // owns the strip: a silent host that never sent a shutdown command (a
    // crash/unplug) still goes dark on the timeout. The shutdown replay drives
    // its own blank, so don't pre-empt it.
    if (hostSeen && strip && !blanked && !shuttingDown &&
        now - lastFrameMs > HOST_TIMEOUT_MS)
    {
        blankStrip();
        blanked = true;
    }

    unsigned long sinceGood =
        now - (lastHuntMs > lastFrameMs ? lastHuntMs : lastFrameMs);

    // hunt for the host's baud until it's found (including all through the
    // power-on replay — that's exactly when we want to lock on). Don't hunt
    // once the host has intentionally gone (shutdown): there's nothing to lock
    // onto and we'd disturb the animation.
    if (!shuttingDown && receiver.bytesSinceValid() >= HUNT_MIN_BYTES &&
        sinceGood > HUNT_AFTER_MS)
    {
        baudIdx = (baudIdx + 1) % NUM_BAUDS;
        currentBaud = BAUDS[baudIdx];
        Serial.updateBaudRate(currentBaud);

        while (Serial.available())
            Serial.read();

        // drop any half-frame caught at the old rate and zero the byte counter,
        // so the next hunt is timed from a clean scan
        receiver.reset();
        lastHuntMs = now;
    }

    // the replay owns the strip before the host's first frame (power-on) and
    // during a shutdown after its last. Player::done() holds the final frame.
    if (((!hostSeen) || shuttingDown) && !player.done() && strip)
    {
        if (const uint8_t* px = player.tick(now))
        {
            // stamp the slot's reserved id so the handoff is an ordinary id
            // change: shutdown frames dissolve in over the last live frame
            // (replayXms); boot frames carry no fade of their own (xms 0) — the
            // first live frame dissolves over the boot recording's last frame,
            // using that live frame's own crossfade duration
            if (shuttingDown)
                show(proto::ANIM_SHUTDOWN, active.count, replayXms, px);
            else
                show(proto::ANIM_BOOT, active.count, 0, px);
        }

        // the shutdown recording ends on its own near-black frame; blank once
        // it's done so the strip goes truly dark
        if (player.done() && shuttingDown)
            blankStrip();
    }
}

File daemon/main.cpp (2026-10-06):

#include <stdio.h>
#include <string.h>
#include <time.h>
#include <signal.h>
#include <sys/stat.h>
#include <thread>
#include <chrono>
#include <vector>
#include <initializer_list>
#include <memory>
#include <functional>
#include "config_check.hpp"
#include "config_edit.hpp"
#include "effect.hpp"
#include "fans.hpp"
#include "power_remote.hpp"
#include "strip_remote.hpp"
#include "motion.hpp"
#include "pwmout.hpp"
#include "rules.hpp"
#include "sdnotify.hpp"
#include "steam.hpp"
#include "serial_sink.hpp"
#include "virtual_sink.hpp"
#include "recorder.hpp"

// set from a signal handler; the render loops watch it so a SIGTERM
// from systemd (or Ctrl-C) breaks out and lets us tell the receiver to
// play the shutdown effect before we exit
static volatile sig_atomic_t g_stop = 0;
static void onStop(int) { g_stop = 1; }

// SIGHUP (`systemctl reload`): re-read the config now, without waiting for
// the file watch below to notice a change
static volatile sig_atomic_t g_reload = 0;
static void onReload(int) { g_reload = 1; }

// the config file's modification time as seconds (0 when it can't be
// stat'ed), for the live-reload watch in the rules loop
static double fileMtime(const char* path)
{
    struct stat st;
    if (stat(path, &st) != 0)
        return 0;
    return st.st_mtim.tv_sec + st.st_mtim.tv_nsec / 1e9;
}

// one top-level config value, or a Null for an absent key — so two configs
// can be compared block by block with json::equal
static const json::Value& topLevel(const Config& cfg, const char* key)
{
    static const json::Value none;
    const json::Value* v = cfg.root().find(key);
    return v ? *v : none;
}

// are two configs identical apart from the named top-level blocks? The
// reload uses it with the blocks that don't feed the strip (each module names
// its own): a change confined to those — a curve or a hold time edited by
// hand, the common case now that the dashboard writes the same file — must
// not disturb the running effect.
static bool sameExcept(const Config& a, const Config& b, std::initializer_list<const char*> blocks)
{
    json::Value x = a.root(), y = b.root();
    for (json::Value* v : {&x, &y})
        for (const char* key : blocks)
            for (auto it = v->members.begin(); it != v->members.end(); ++it)
                if (it->first == key)
                {
                    v->members.erase(it);
                    break;
                }
    return json::equal(x, y);
}

static double now_seconds()
{
    timespec ts;
    clock_gettime(CLOCK_MONOTONIC, &ts);
    return ts.tv_sec + ts.tv_nsec / 1e9;
}

// is the whole machine going down, or just this service? systemd reports
// "stopping" once shutdown.target (poweroff, reboot, halt) is under way, which
// is when our SIGTERM is part of a power-off. Anything else — a restart, a
// stop, a Ctrl-C, no systemd at all — reads as "no", the safe answer: the
// receiver then treats the silence like any other and the fans fall back.
static bool systemStopping()
{
    FILE* f = popen("systemctl is-system-running 2>/dev/null", "r");
    if (!f)
        return false;

    char buf[32] = {0};
    if (!fgets(buf, sizeof buf, f))
        buf[0] = 0;
    pclose(f);

    return strncmp(buf, "stopping", 8) == 0;
}

// wrap already-corrected recording pixels into a wire frame (--preview): the
// values are post-LUT 8.8 fixed point exactly as recorded, so unlike Strip
// they must not be re-corrected — they go out as a deep frame verbatim.
// Checksum is XOR of the header and pixel bytes, matching common/protocol.hpp.
// A recording is one continuous animation (its own intro/loop is baked in), so
// every frame carries the same anim id (0) and no crossfade (xms 0) — the
// viewer plays it straight through with no dissolves.
static std::vector<uint8_t> framePixels(uint8_t pin, uint16_t count,
                                        const uint8_t* px)
{
    std::vector<uint8_t> f;
    f.reserve(proto::PIX_HEADER + (size_t)count * 6 + 1);

    f.push_back(proto::SYNC0);
    f.push_back(proto::SYNC1_16);
    f.push_back(pin);
    f.push_back(count & 0xFF);
    f.push_back(count >> 8);
    f.push_back(0); // anim lo
    f.push_back(0); // anim hi
    f.push_back(0); // xms lo
    f.push_back(0); // xms hi

    // the four zero header bytes XOR out, so the sum is pin/count/pixels
    uint8_t sum = pin ^ (uint8_t)(count & 0xFF) ^ (uint8_t)(count >> 8);

    for (size_t i = 0; i < (size_t)count * 6; i++)
    {
        f.push_back(px[i]);
        sum ^= px[i];
    }

    f.push_back(sum);
    return f;
}

// render the receiver's power-on/shutdown effects (the "power_on" and
// "shutdown" blocks) to frames and stream them over so the receiver can store
// and replay them — at the next power-on (before the daemon is up) and on
// shutdown (after it exits). The receiver runs no effect code of its own;
// these recordings are the only thing it plays standalone. Done once at
// startup, so an edited effect is picked up on the next daemon (re)start and
// shown one power cycle later. A missing block is simply not recorded. The
// recording uses `strip` purely as a correction canvas — by value inside
// record(), so the daemon's own Strip is untouched. Broadcast to every sink;
// only the serial transport acts on commands, the rest no-op (see
// daemon/output/sink.hpp).
static void recordAndUpload(const Config& cfg, const Strip& strip,
                            std::vector<std::unique_ptr<Sink>>& sinks,
                            const std::function<void()>& keepalive = {})
{
    const struct { const char* path; uint8_t id; } slots[] = {
        {"power_on", proto::SLOT_POWER_ON},
        {"shutdown", proto::SLOT_SHUTDOWN},
    };

    for (auto& slot : slots)
    {
        rec::Recording r;

        if (rec::record(cfg, strip, slot.path, r))
        {
            fprintf(stderr, "recorded %s: %u frames @ %u ms; uploading\n",
                    slot.path, r.frameCount, r.frameMs);
            rec::upload(sinks, slot.id, r, keepalive);
        }
    }
}
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

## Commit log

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2026-06-10 esp32: blank old strip before re-init on count/pin change
    WS2812 pixels latch their last value, so when a frame arrives with a
    smaller LED count (or a different pin) the pixels beyond the new range
    stayed frozen on their last color. Blank the previous strip before
    rebuilding it; count increases skip the blank since the larger frame
    overwrites everything anyway.
    [esp32_receiver.ino]
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2026-06-12 esp32: standalone power-on breathe until the first host frame
    The OS takes a while to start the daemon, so the receiver now runs
    the host's idle warm-amber breathe from power-on instead of sitting
    dark, through the same gamma/brightness curve the host applies.
    Strip geometry comes from the last valid frame (persisted in NVS
    alongside the baud), falling back to strip.leds/strip.pin baked in by
    `make flash` like HOST_BAUD already was; strip.brightness is baked in
    too. The breathe never resumes after the host goes quiet — that means
    shutdown or crash, where the timeout blank (now gated on having seen
    the host at all) is the right answer.
    [esp32_receiver.ino]
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2026-06-15 strip: global white balance and per-channel gamma
    Add strip.white_balance (RRGGBB), a per-channel linear gain that
    corrects an overall color cast from a diffuser/filter in front of the
    strip. Being linear, it holds across the whole brightness range. Split
    the shared gamma LUT into three so strip.gamma also accepts three
    space-separated values, the knob for a tint that only shows at the dim
    end (the WS2812 dies not tracking near their PWM floor).
    Mirror white balance into the receiver's standalone power-on breathe so
    it matches the daemon's frames; make flash bakes it in alongside
    brightness. Document both knobs and a dial-in procedure in the README.
    [esp32_receiver.ino, ws2812_serial.hpp]
2026-06-15 esp32: run configurable boot/shutdown effects on the receiver
    Graceful shutdown was missing: when the host stopped, the strip held its
    last frame until power died. The receiver is independently powered and
    outlives the host, so play the shutdown animation there.
    - Daemon catches SIGTERM/SIGINT and sends a CMD_SHUTDOWN command frame,
    then exits immediately instead of blocking systemd. The receiver plays
    its shutdown effect to completion on its own clock.
    - Share the actual effect code with the firmware instead of hand-keeping
    a copy: extract the color LUT (color_lut.hpp) and a Strip typedef so
    effects render against WS2812Serial on the host and Esp32Strip on the
    ESP32. effect.hpp p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
    [esp32_receiver.ino, main.cpp, protocol.hpp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]
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2026-06-15 rules: drop global hold_seconds, make hold a per-rule knob
    The global hold_seconds was an invisible default applied to every rule
    that didn't override it. Remove it: a rule's "hold" now stands alone and
    defaults to 0 (switch immediately), so a rule that wants debouncing sets
    its own. config.json carries an explicit "hold": 0 on every rule so the
    knob is discoverable inline.
    [main.cpp]
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2026-06-15 restructure by execution target; reuse the parser for build config
    - group source into shared/ (daemon + firmware), host/ (daemon-only),
    firmware/, and vendor/; includes stay path-less so the receiver's
    flat copy is unaffected and the host build just adds -I per dir
    - add `led --config-get <config> <path>` and use it in the Makefile
    instead of sed-scraping JSON, so build values can't drift from how
    the daemon reads the same file
    - dedupe the two EffectConfig getColor backends behind parseHexColor
    - drop the implicit cpu_temp fallback rule: with no rule matching the
    daemon sends nothing and the strip goes dark
    [esp32_receiver.ino, main.cpp, protocol.hpp]
2026-06-15 receiver: hoist SlotConfig above the first function
    arduino-cli inserts its generated prototypes just before the first
    function definition. parseSlot/loadSlot/startStandalone return or take
    SlotConfig, so those prototypes referenced the struct before its
    definition lower in the file, failing with "SlotConfig does not name a
    type". Move the struct above initStrip so it's visible at that point.
    [esp32_receiver.ino]
2026-06-15 steam: add --steam-status to dump download detection
    A blank steam_download bar has been hard to diagnose remotely because
    the scan in steam.hpp gives no visibility into which libraries it found
    or why a manifest was or wasn't counted as an active download. Add a
    one-shot verbose scan, wired to a --steam-status flag, that prints the
    matched library dirs, each appmanifest's StateFlags and byte counters,
    whether the addManifest filter counts it (with the reason when it
    doesn't), and the resulting percent.
    [main.cpp]
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2026-06-18 effects: smoother, less static visuals + crossfade between effects
    load: soft-tipped bars washed with aurora-style cool-hue curtains and a
    brightness shimmer, so a GPU pinned at 100% keeps drifting instead of
    sitting as a static block; drops the thermal green->red ramp.
    cpu_temp: soft tip + slow shimmer (thermal ramp kept; color means temp).
    fire: gentler flicker blended with a slow flowing drift.
    steam_download: shallow uniform breath between flow sweeps.
    main/ws2812_serial: crossfade between effects, dissolving from the last
    displayed frame into the new effect over transition_seconds (default
    0.6, 0 = instant). Wall-clock timed; first effect after startup is
    immediate.
    [main.cpp, ws2812_serial.hpp]
2026-06-18 boot/shutdown: hold through the OS power transitions
    boot now plays its CRT power-on intro and then holds a living glow
    indefinitely instead of fading to black on a fixed timer. The daemon
    doesn't connect until after limine and the OS come up, so any fixed
    duration ended early and left the strip dark mid-boot. boot.finished()
    now always returns false; the receiver drops it on the host's first
    frame. Config key renamed duration_seconds -> intro_seconds (falls back
    to the old key).
    shutdown's dying phosphor glow is lengthened (2s -> 5s, collapse kept a
    snappy ~0.5s) so it lingers through the power-down instead of blanking
    seconds early. It still finishes and goes dark, since the strip is
    inde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
    [ws2812_serial.hpp]
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2026-06-22 color: temporal dither the LUT output so slow gradients stop stepping
    Keep the gamma/wb/brightness result at 8 extra fractional bits and dither
    the final round-down with a per-pixel, per-frame ordered threshold. Gamma
    plus a low brightness otherwise collapse the 256 input codes onto a few
    dozen outputs, so a slowly drifting effect (aurora especially) holds flat
    for many frames then jumps a whole code -- visible stepping. The dither
    toggles the LSB between frames; the eye averages it back to the in-between
    value, so the drift glides. The frame counter is bit-reversed for fast
    temporal spread, offset per pixel/channel to avoid whole-strip flicker.
    Host bumps the counter in beginFrame(); the r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
    [esp32_receiver.ino, ws2812_serial.hpp]
2026-06-22 effects: expose frame_ms so frame rate is configurable per-effect or globally
    Add setFrameDelay() to the Effect base: each effect resolves frame_ms in
    init() (rule settings first, then top-level config as a global default,
    else its own built-in). Defaults unchanged -- 33ms for the steady visuals,
    16ms for the one-shot/transition ones. cycle keeps delegating to its sub.
    Effects that integrate state per frame (load, comet, twinkle,
    steam_download) read frameDelayMs() as their dt, so the one value drives
    both refresh rate and timestep: lowering frame_ms smooths motion without
    changing its speed.
    [twinkle.cpp]
2026-06-22 effects: calm flowing redesign on shared palette + motion helpers
    Replace fire/twinkle with calm, smooth effects and push the whole set
    toward the comet/aurora feel: continuous eased motion, soft edges,
    multi-frequency fields, and configurable palettes.
    Shared building blocks:
    - color::Gradient: multi-stop palette sampled 0..1 from a hex spec
    - motion.hpp: flow, shimmer, smootherstep ease, eased pingpong, and a
    1D value-noise field blended into the flowing effects for organic drift
    Effects:
    - fire -> ember: warm palette flow (no random flicker)
    - twinkle -> drift: soft glows wandering over a dark base
    - breathe: adds a drifting brightness band
    - comet: eased turnaround + optional mirrore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
    [main.cpp, twinkle.cpp]
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2026-06-23 esp32: record/replay boot+shutdown instead of on-device effects
    The receiver no longer compiles or renders any effect code. The daemon
    renders the configured power-on/shutdown effects through its own Strip
    (so the pixels are byte-identical to live hardware output), captures the
    frames, and streams them; the receiver stores each in LittleFS and
    replays them. Iterating on the boot/shutdown animations no longer needs
    a reflash — edit config, restart the daemon, see it next power cycle.
    - shared/recording.hpp: Recording (flat buffer + on-wire/on-flash byte
    codecs + hash), RecordingReceiver (CMD_REC_* accumulator + skip/size
    guards), Player (replay stepper: timing, loop vs hold, loopStart)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
    [esp32_receiver.ino, main.cpp, protocol.hpp]
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2026-06-26 crossfade: move dissolves to the receiver, driven by a per-frame anim id
    Crossfading between animations no longer lives in the daemon's render loop;
    it's owned by whoever drives a display (the ESP32 firmware, and the viewer),
    so it also covers handoffs the host can't see across: the boot recording into
    the first live frame, and the live picture into the shutdown recording.
    Every pixel frame now carries the rendering effect instance's id and a global
    crossfade duration (shared/protocol.hpp, 9-byte header). The receiver keeps the
    last frame it showed and dissolves whenever the id changes, via one shared
    fader (shared/fade.hpp). cycle reports its active child's id, so its internal
    hops crossfa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
    [esp32_receiver.ino, main.cpp, protocol.hpp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]
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2026-06-30 firmware: ship sketch-local partitions.csv to bypass broken {build.partitions} lookup
    arduino-esp32 3.3.x leaves the literal {build.partitions} unexpanded in the
    tools/partitions/{build.partitions}.csv copy once any FQBN menu option (e.g.
    CDCOnBoot) is set, and neither PartitionScheme=default nor --build-property
    build.partitions=default overrides it. A partitions.csv in the sketch folder is
    copied directly by the platform, so that lookup never runs. Standard default
    4MB layout with the 'spiffs' partition the firmware's LittleFS recordings use.
    [partitions.csv]
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2026-07-01 firmware: replace arduino-cli/.ino with native ESP-IDF project
    The receiver firmware was an Arduino .ino built via arduino-cli, which caused
    recurring trouble (FQBN/board detection, {build.mcu}/{build.partitions}, broken
    upload). Rewrite it as a native ESP-IDF project — no arduino-cli, no Arduino
    framework. The shared common/*.hpp (protocol, framing, recording, crossfade)
    are untouched and now compile straight from ../common on the include path.
    Device-specific ports:
    Freenove WS2812 lib -> espressif/led_strip (RMT, GRB, 2.x API)
    Preferences -> nvs
    LittleFS -> joltwallet/littlefs
    Serial -> driver/uart (ESP32) | usb_serial_jtag (C3), by target
    mill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
    [partitions.csv]
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2026-07-06 color: dither on the receiver at strip-refresh rate, not on the host
    At low brightness the corrected output collapses onto a few dozen codes,
    and the host-side per-frame dither could only hide that badly: spatial
    dithering turned slow animations into uncoordinated full-code pops (one
    code at the dim end is a 2x luminance jump), and temporal dithering at
    60 fps shimmered. The rounding decision has to happen somewhere fast
    enough to be invisible — which is the receiver, not the daemon.
    So the daemon stops dithering entirely and ships the correction LUT's
    full 16-bit values on the wire: a new deep pixel frame (SYNC1_16, same
    header, little-endian 8.8 fixed point per channel). The firmware ke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
    [main.cpp, protocol.hpp]
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2026-07-11 firmware: store recordings atomically, distrust truncated files
    saveRecording wrote the header (which carries the upload-skip hash)
    first and the pixel data after it, with nothing checked. A write
    interrupted partway - a power cut, or esptool yanking the chip into
    the bootloader for a reflash mid-upload - left a file whose header
    was valid but whose data was truncated. loadRecording correctly
    rejected such a file, so both standalone replays went dark; but
    storedHash vouched for it (it read only the header), so every later
    upload was skipped as "unchanged" and the corruption became
    permanent - no number of daemon restarts or config re-uploads could
    heal it. Exactly this froze a C3's boot/shut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
    [main.cpp]
2026-07-11 firmware: replay the power-on recording when the USB host restarts
    The power-on replay only ran between a chip reset and the first host
    frame. That covers a board that actually loses power with its host -
    but a C3 on USB Serial/JTAG often doesn't: standby VBUS keeps it
    running while the host is off, so it never resets, hostSeen stays
    latched from the previous session, and the boot recording never
    plays again. The strip just sat dark from power button to daemon.
    A running host's USB controller sends SOF keepalives every
    millisecond, and the driver already tracks their presence
    (usb_serial_jtag_is_connected). When they stop for HOST_GONE_MS and
    later return, treat that as the power-on it effe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
    [main.cpp]
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2026-07-11 firmware: never dither against true black — round sub-code values instead
    Fade-to-black tails sweep channels below code 1, where the ordered dither
    renders the fraction as code-1 flashes on an unlit LED at fraction x latch
    rate — tens of Hz at 100% contrast. A black diffuser hides the flashes; a
    white one shows every blink as jitter. Round sub-code values to nearest at
    the latch instead, so a tail ends on a steady code 1, then true zero.
    Dithering between lit codes is unchanged.
    [main.cpp]
2026-07-11 firmware: put a blink-rate floor on the dither, latch twice as fast
    A dithered fraction pulses at fraction x latch rate — exact on average,
    but unbounded below: value 2.02 showed code 3 six times a second, and at
    dim codes one step is a big relative jump (code 2->3 is +50%), so
    near-code dim pixels twinkled visibly through a pale diffuser.
    Fractions whose pulse (or gap) rate would land below 100 Hz now round to
    the nearest code instead: a steady, slightly-off level in place of a slow
    blink. The floor adapts to the measured latch gap, subsuming the old
    fixed SLOW_LATCH_US cutoff — starved loops degrade to rounding, never
    flicker. The serial read block and refresh gate drop to 1 ms so the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
    [main.cpp]
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2026-07-13 firmware: split main.cpp into modules — the LED service gets its own task
    Pure restructure, no functional change: link/prefs/render/rec_store split
    out of the 900-line main.cpp, and the receiver loop moves off app_main
    into its own prioritized FreeRTOS task so future features (own tasks)
    can't stall the ~1 kHz latch cadence the dither depends on. main.cpp is
    now just substrate bring-up (NVS, LittleFS) plus led::start().
    [led_service.cpp, link.cpp, main.cpp]
2026-07-15 firmware: ATX power switch — the receiver stands in for the PS_ON# jumper
    Powered from the PSU's 5VSB rail, the receiver drives the ATX PS_ON#
    line open-drain: tap a momentary button to start the PSU, hold 5 s to
    force a wedged machine off, and an optional ADC sense wire (BC-250
    TPMS1 pin 9) follows a graceful OS shutdown down and releases a board
    that never came up. Its own task and NVS namespace (power_switch.*);
    the LED service is untouched. The intended PSU state is persisted and
    re-asserted through any reset that isn't a true power-on, with
    gpio_hold latching the pin through the reset itself.
    The wiring lives in a new 4 KB pwrcfg data partition, not the app
    image, so it's chosen at f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
    [partitions.csv]
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2026-07-27 power switch: PS_ON# drives a 2N7000 MOSFET gate — a 3.3 V pad can't pull the PSU's 5 V line
    Direct open-drain drive doesn't work: PS_ON# is pulled to 5 V inside the
    PSU, so releasing the pad back-feeds its clamp diode and never reaches a
    clean off. A low-side N-channel MOSFET (2N7000) level-shifts it instead.
    applyPsOn() now drives the gate active-high push-pull (GPIO_MODE_OUTPUT,
    level 1 = MOSFET on = PS_ON# grounded = PSU on) rather than open-drain.
    A ~100 kOhm gate pull-down keeps the MOSFET off whenever the pad isn't
    driving (pre-boot, reset, the PWR=off release path). Fresh-pad level 0 is
    now gate-low/PSU-off, so the old spurious-power-on-pulse concern is gone.
    README: MOSFET wirin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
    [power_switch.cpp, power_switch.hpp]
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2026-07-28 power switch: sense moves to GPIO0 — GPIO2 must strap high, and TPMS1 pin 9 is a dead rail
    The BC-250's connector documentation identifies TPMS1 pin 9 as "3V", the
    board's main 3.3 V rail — not the soft, high-impedance signal line the
    comments claimed. That makes it the right thing to sense (the board runs on
    12 V alone and derives both rails on board, so while we hold PS_ON# the 12 V
    input and TPMS1's 3VSB on pin 15 stay up, and only this rail collapses when
    the OS powers itself down) but it makes GPIO2 the wrong pin to read it with.
    GPIO2 is a C3 strapping pin that must read HIGH at reset to select SPI boot,
    and a dead rail sits firmly at 0 V — it is not a floating line that might
    d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
    [power_switch.cpp, power_switch.hpp]
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2026-07-29 power switch: sense back on GPIO2, and holding the button now suspends it
    The GPIO0 sense default was hygiene — GPIO2 is a C3 strapping pin, and
    Espressif recommend pulling it up, which a line grounded whenever the
    machine is off plainly doesn't. But the pin was never the problem (boot
    mode is GPIO9/8; GPIO2 "does not determine" it, and it boots fine on the
    real board), and the cost of a default that doesn't match the wire in the
    machine turned out to be severe: flashed with the wire still on GPIO2,
    sense reads a dead pin, so the 10 s boot timeout cuts the PSU on every
    boot — and the machine can no longer stay up long enough to reflash the
    config that would fix it. So: GPIO2, the pin thi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
    [power_switch.cpp, power_switch.hpp]
2026-07-29 receiver: the baud hunt shredded every recording upload
    Nothing the daemon recorded ever reached flash, so the boot and shutdown
    animations never played on any board — the strip just sat dark until the
    first live frame, and the "upload" lines in journalctl were the host
    happily talking into a hole.
    The hunt (led_service.cpp) decides the host must be at another rate from
    "bytes keep arriving but nothing decodes", and it measured that from the
    last *pixel* frame. But the daemon's first traffic after it starts is the
    recording upload: hundreds of CMD_REC_FRAMEs and no pixels at all. So a
    receiver that hadn't seen a pixel frame since reset had lastFrameMs = 0,
    the 500 ms condition was permane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
    [led_service.cpp, link.cpp, main.cpp]
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2026-07-29 power switch: a short press asks the host to shut itself down
    The gesture was free — a short press while the machine was up did nothing —
    and it's the one every PC power button makes. Now it means what it means
    everywhere else: shut the OS down gracefully.
    Nothing on the receiver can do that, so it asks. New REQ_SYNC frame (0x59,
    req + nonce + xor), the first thing the receiver ever sends unsolicited;
    the daemon answers with CMD_REQ_ACK echoing both and runs its configured
    command (sinks.serial.power_button_command, default `systemctl poweroff`).
    Repeats every 500 ms until answered, because one 8-byte frame can be lost
    and "please power off" is idempotent. CMD_SHUTDOWN counts as an answ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
    [led_service.cpp, power_switch.cpp, power_switch.hpp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]
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2026-08-25 flash: the merged image wiped NVS, so reflashing cut the host's own power
    The CI merged image 0xFF-pads the gap between the partition table and the
    app — which is exactly the nvs partition. `make flash` wrote it whole at
    0x0, erasing the power switch's saved "PSU is on" intent every time: the
    gpio_hold rode through the flash fine, then the freshly booted firmware
    read savedOn=0 and deliberately released PS_ON#, hard-cutting the machine
    the flash ran on (corrupting its filesystem — this is the reflash landmine
    from the README, finally root-caused).
    Two-sided fix: `make flash` now slices the image around the nvs hole and
    writes two segments, so NVS (incl. the saved baud/geometry) survives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
    [power_switch.cpp]
2026-08-25 fans: the boost re-fired on every daemon restart — key it to the power-on event
    The boost was an edge detector on the sense rail, and it deliberately fired
    when the rail was already up at task start ("re-priming after a crash/reflash
    is a feature"). But something warm-resets the receiver whenever the daemon
    connects, and after any warm reset the sense line reads down through one
    debounce before coming back up — an edge indistinguishable from a real
    power-on. Net effect: five seconds of full pump on every systemctl restart.
    Now the power switch counts its power-on events (pwr::powerOnSeq(), bumped
    only by powerOn() — never by start()'s warm-reset re-hold), the fan task arms
    its boost o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
    [fan.cpp, fan.hpp, power_switch.cpp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]
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2026-08-26 recordings: stream uploads and replay through flash, never RAM
    The power-on animation was never stored: uploading it made the receiver
    reserve ~118 KB of contiguous RAM (the whole recording, buffered before
    the flash commit), and with C++ exceptions off a failed allocation is an
    abort — the C3 panic-rebooted at every daemon connect, eating the
    power_on upload (always first on the wire) while the small shutdown
    upload landed after the reboot and stored fine. Likely also the
    long-undiagnosed "warm reset at connect".
    Now nothing holds a recording in RAM on the receiver. Uploads append
    each vetted frame to the slot's temp file as it arrives (same atomic
    rename commit as before), with integrit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
    [led_service.cpp]
2026-08-26 ble remote: power the box from a phone, no WiFi anywhere
    The receiver (on 5VSB) now advertises a small NimBLE GATT service so a
    phone can work the power switch from radio range: power on (the same
    path as a button press — fan boost, boot animation, sense confirm),
    the graceful ask-the-host shutdown, and the hold's hard PSU cut for a
    crashed machine. Advertising runs in both PSU states — a wedged box
    must be reachable — 300 ms intervals while off, ~1.3 s while on so the
    radio stays a rounding error next to the strip's latch cadence.
    Same shape as the other receiver features: own task, config in a new
    4 KB blecfg partition written at flash time (make flash BLE=on
    BLE_TOKEN=... / make fl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
    [partitions.csv]
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
